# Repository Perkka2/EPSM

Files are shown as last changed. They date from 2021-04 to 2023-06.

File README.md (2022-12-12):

# EPSM
 NES Expansion Port Sound Module (Earlier: Expansion Port Sound Generator)

### An expansion sound card for the Nintendo Entertainment System

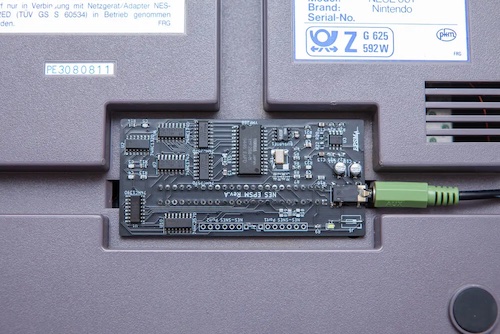
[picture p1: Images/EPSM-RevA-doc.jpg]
EPSM RevA


It uses an Yamaha YMF288 Soundchip that gives a lot of new audio capabilities to the NES.

## Features of YMF288:
* 3 Pulse Channels with Envelope and Noise
* 6 4OP FM Channels with hard panning stereo.
* 6 Rythm channels featuring 6 different ADPCM Drum Recordings with Hard Panning Stereo support
* 2 Timed IRQ's
## Added features of the EPSM
* Forwards expansion audio from supported gamecarts
  * Original Famicom expansion audio games with compatible adapter
  * PowerPak
  * EverDrive N8
  * EverDrive N8 Pro
  * Other carts using EXP2, EXP6 or EXP9 to output audio
* Alternative 3.5mm jack for Stereo output
  * EPSM Audio forwarding to the NES RCA/RF outputs are disabled when the 3.5mm jack is plugged in
  * NES Audio and Cart Expansion audio plays as Dual Mono on the 3.5mm jack.

## Tools
* Mesen-X: Supports playback of EPSM using any mapper.
* FamiStudio: Allows for music creation for the EPSM and has both ROM and NSF export options.

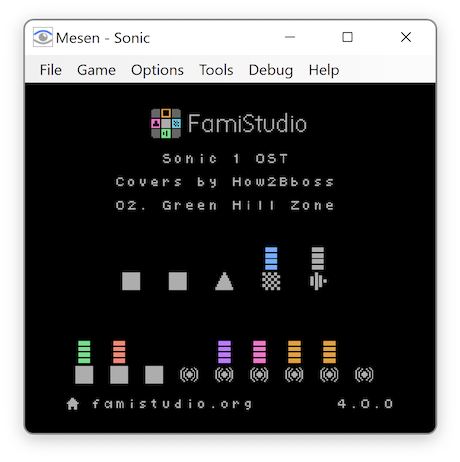
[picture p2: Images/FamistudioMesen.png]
Famistudio_and_Mesen


## Usage
* [Addressing](Docs/Addressing.md)
* [Addressing Fiskbit's Fallback Handler](Docs/Fiskbit-FallbackHandler.md)
* [NESDev wiki](https://www.nesdev.org/wiki/Expansion_Port_Sound_Module)
* [N8 Pro Mappers with EPSM Addressing](Files/N8ProEPSM.zip)

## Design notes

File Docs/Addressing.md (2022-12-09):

It uses 2 different addressing methods, either using the `$4016 OUT1` latch that exist on both NES and Famicom expansion port.
Or addresing throught the `EXP` pins on the NES or a external address daughterboard on the Famicom

It has two independent addressing modes
Firstly it got an addressing mode using the expansion port OUT1 signal

The OUT1 latch signal is used as a clock for the data transfer, it latches on writes to $4016.
On the OUT1 rising edge it takes CPU D2-D7 data bits D4-D7 and using it as the High Nibble
Data bit D2 is used to define if it's Register or Data
Data bit D3 is used to define if A1 is set (switching between SSG,Rythm,FM1-3 or FM4-6)

On the falling edge it takes CPU D4-D7 data bits and using it as the Low Nibble.
One important thing to think about is that OUT1 ONLY latches every other cpu cycle. so this needs to stay in sync.

The second addressing mode use addressing through the cartridge EXP pins for the NES, or the cart addressing connector on the Famicom
It uses 5 lines to set Chip Enable, A0 (Register/Data) and A1

### Example

```
EXP8 - EPSM CE1 = CPU A14
EXP3 - EPSM CE2 = ROMSEL
EXP1 - EPSM CE3 = R/W
EXP7 - EPSM A0  = CPU A13
EXP4 - EPSM A1  = CPU A1
```

When connected like this the EPSM will listen to C00x/E00x
C000 for register A1=0, C002 for register A1=1, E000 data A1=0, E002 data A1=1

###  Example code for $4016

```
;address write A1=0
LDA value
PHA
AND #$F0
ORA #$2
STA $4016
PLA
ROL
ROL
ROL
ROL
AND #$F0
STA $4016
;address write A1=1
LDA value
PHA
AND #$F0
ORA #$6
STA $4016
PLA
ROL
ROL
ROL
ROL
AND #$F0
STA $4016
;data write A1=0
LDA value
PHA
AND #$F0
ORA #$A
STA $4016
PLA
ROL
ROL
ROL
ROL
AND #$F0
STA $4016
;data write A1=1
LDA value
PHA
AND #$F0
ORA #$E
STA $4016
PLA
ROL
ROL
ROL
ROL
AND #$F0
STA $4016
```

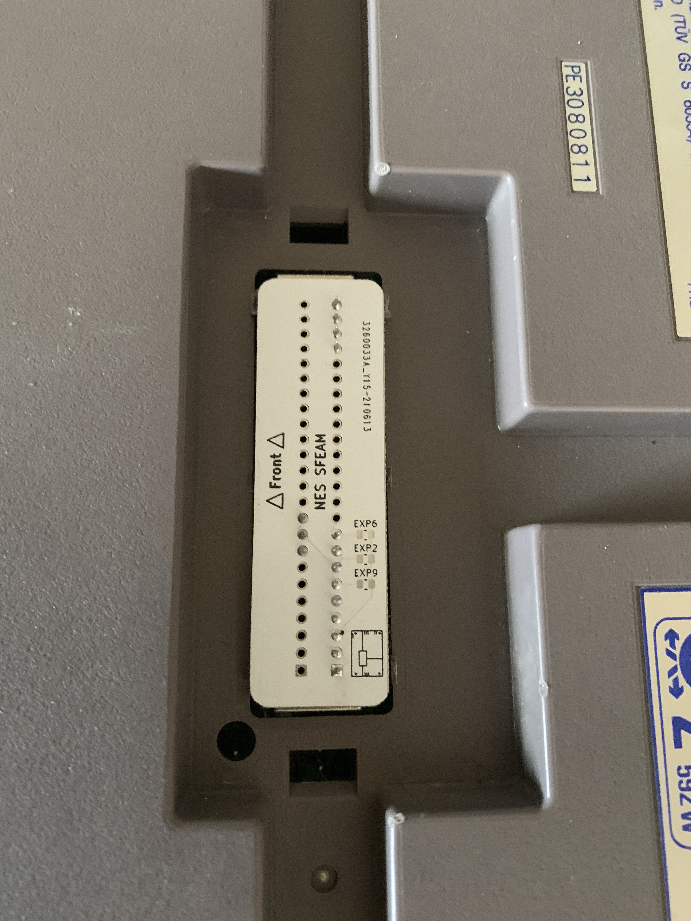
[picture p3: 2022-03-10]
Images/SFEAM_1.JPG

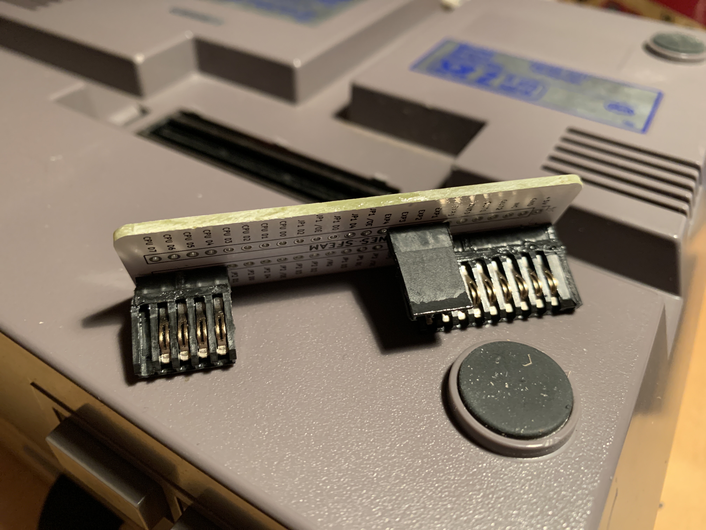
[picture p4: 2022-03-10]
Images/SFEAM_3.JPG

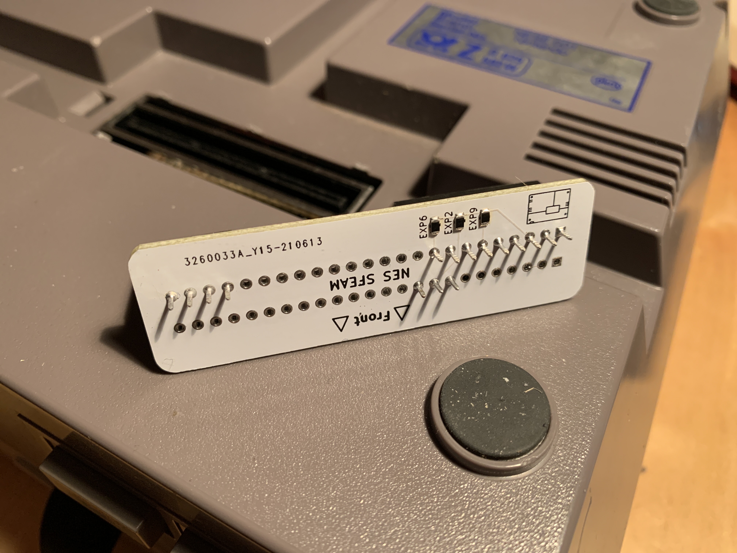
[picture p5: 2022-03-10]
Images/SFEAM_2.JPG

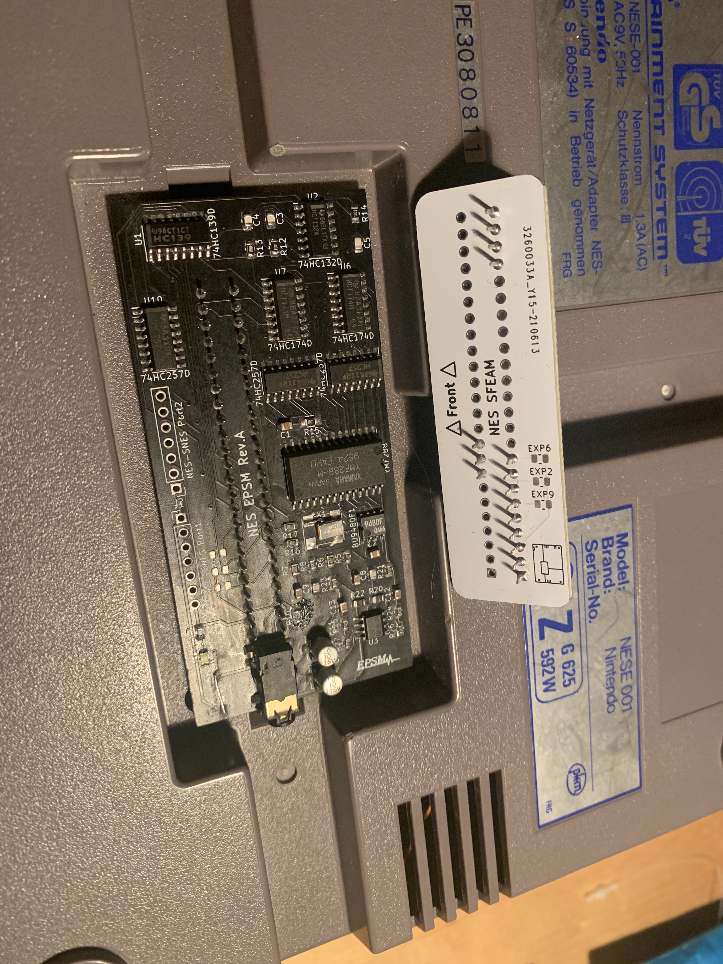
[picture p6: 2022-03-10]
Images/EPSM-RevA and SFEAM.JPG

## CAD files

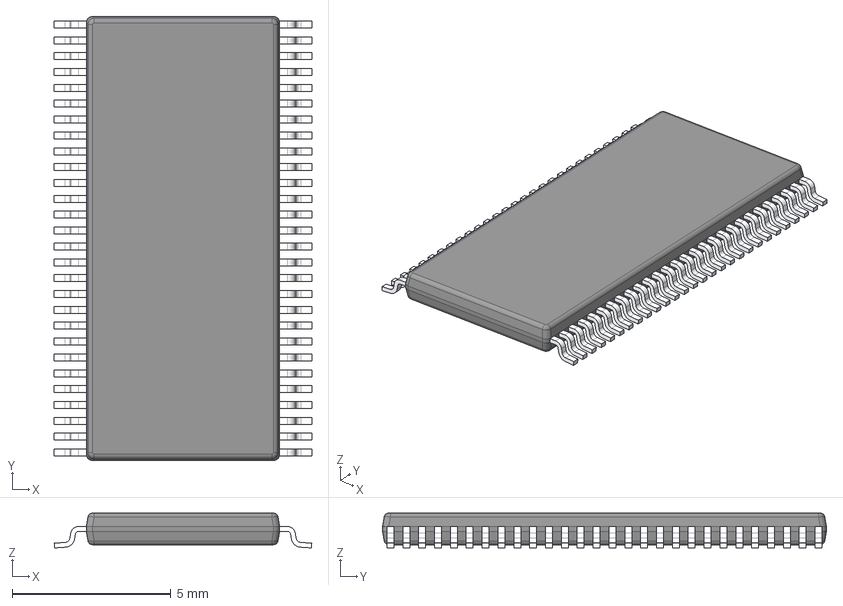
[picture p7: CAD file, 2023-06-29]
Nes Sound Expansion YMF288/eec.models/Texas_Instruments_-_SN74CBTLV16292GR.step
8.12 x 14.0 x 1.10 mm

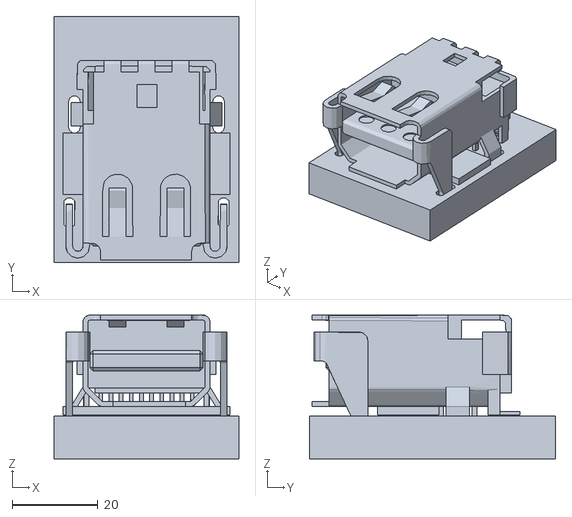
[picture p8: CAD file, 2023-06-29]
Nes Sound Expansion YMF288/Foxconn.models/OBJ_NEW_PCB.obj
43.0 x 57.2 x 33.4

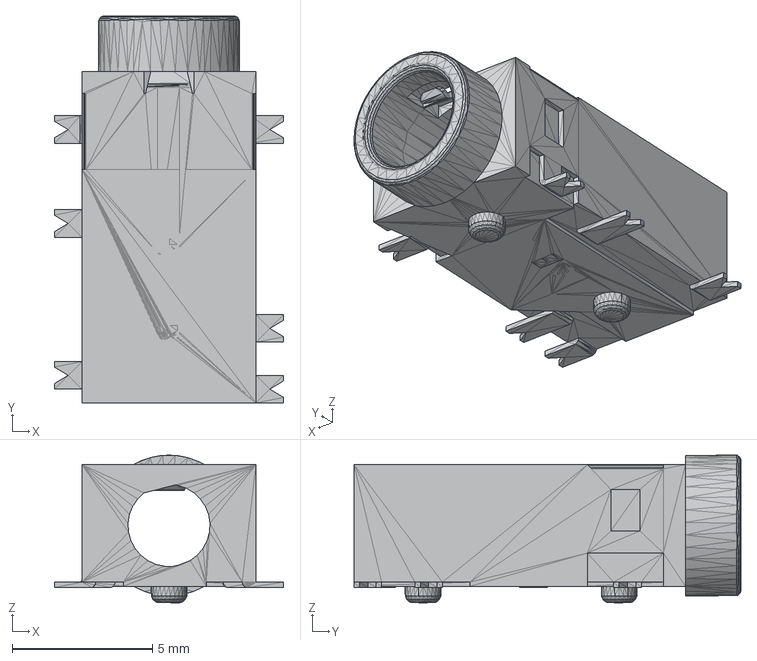
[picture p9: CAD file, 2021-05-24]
Nes Sound Expansion YMF288/walter/conn_av/PJ-342b.step
8.17 x 13.8 x 5.26 mm

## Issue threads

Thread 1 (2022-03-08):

Hello!

zombie343, 2022-03-08:
I've used KICAD and Gerber, but the other files just confuse me. Are these printed circuit boards? Why post on GitHub vs say, OSHpark? I feel like I'm missing something obvious that might be solved by a screenshot.

P.S. thank you for doing this, as I'm modding all of my various NESes, flash carts and converters to support expansion audio

Perkka2, 2022-03-08:
Which files are confusing you? I am having all my NES projects here on GitHub.
There are mainly 3 PCBs here. 2x EPSM's and 1 simple audio mod board to get ordinary expansion audio to the NES without modding the NES

zombie343, 2022-03-09:
Yes! I'm interested in the solderless expansion audio! Could I trouble you for 1-2 pictures? Can I have the solderless expansion board made via OSHpark or PCBWay?

Perkka2, 2022-03-10:
I have now uploaded some example images of the NES version of the EPSM and the SFEAM.

I have used jlcpcb for my boards but i can not see why you would have any issues with other producers

zombie343, 2022-03-11:
Thank you! I'm new to ordering PCBs so I appreciate the pictures and the recommendation!

zombie343, 2022-03-11:
Stupid question: does the console boot into the EPSM instead of the cartridge? Or does this replicate/replay the audio of the plugged-in cart?

Perkka2, 2022-05-18:
Discussion finished on discord

Closed 2022-05-18.

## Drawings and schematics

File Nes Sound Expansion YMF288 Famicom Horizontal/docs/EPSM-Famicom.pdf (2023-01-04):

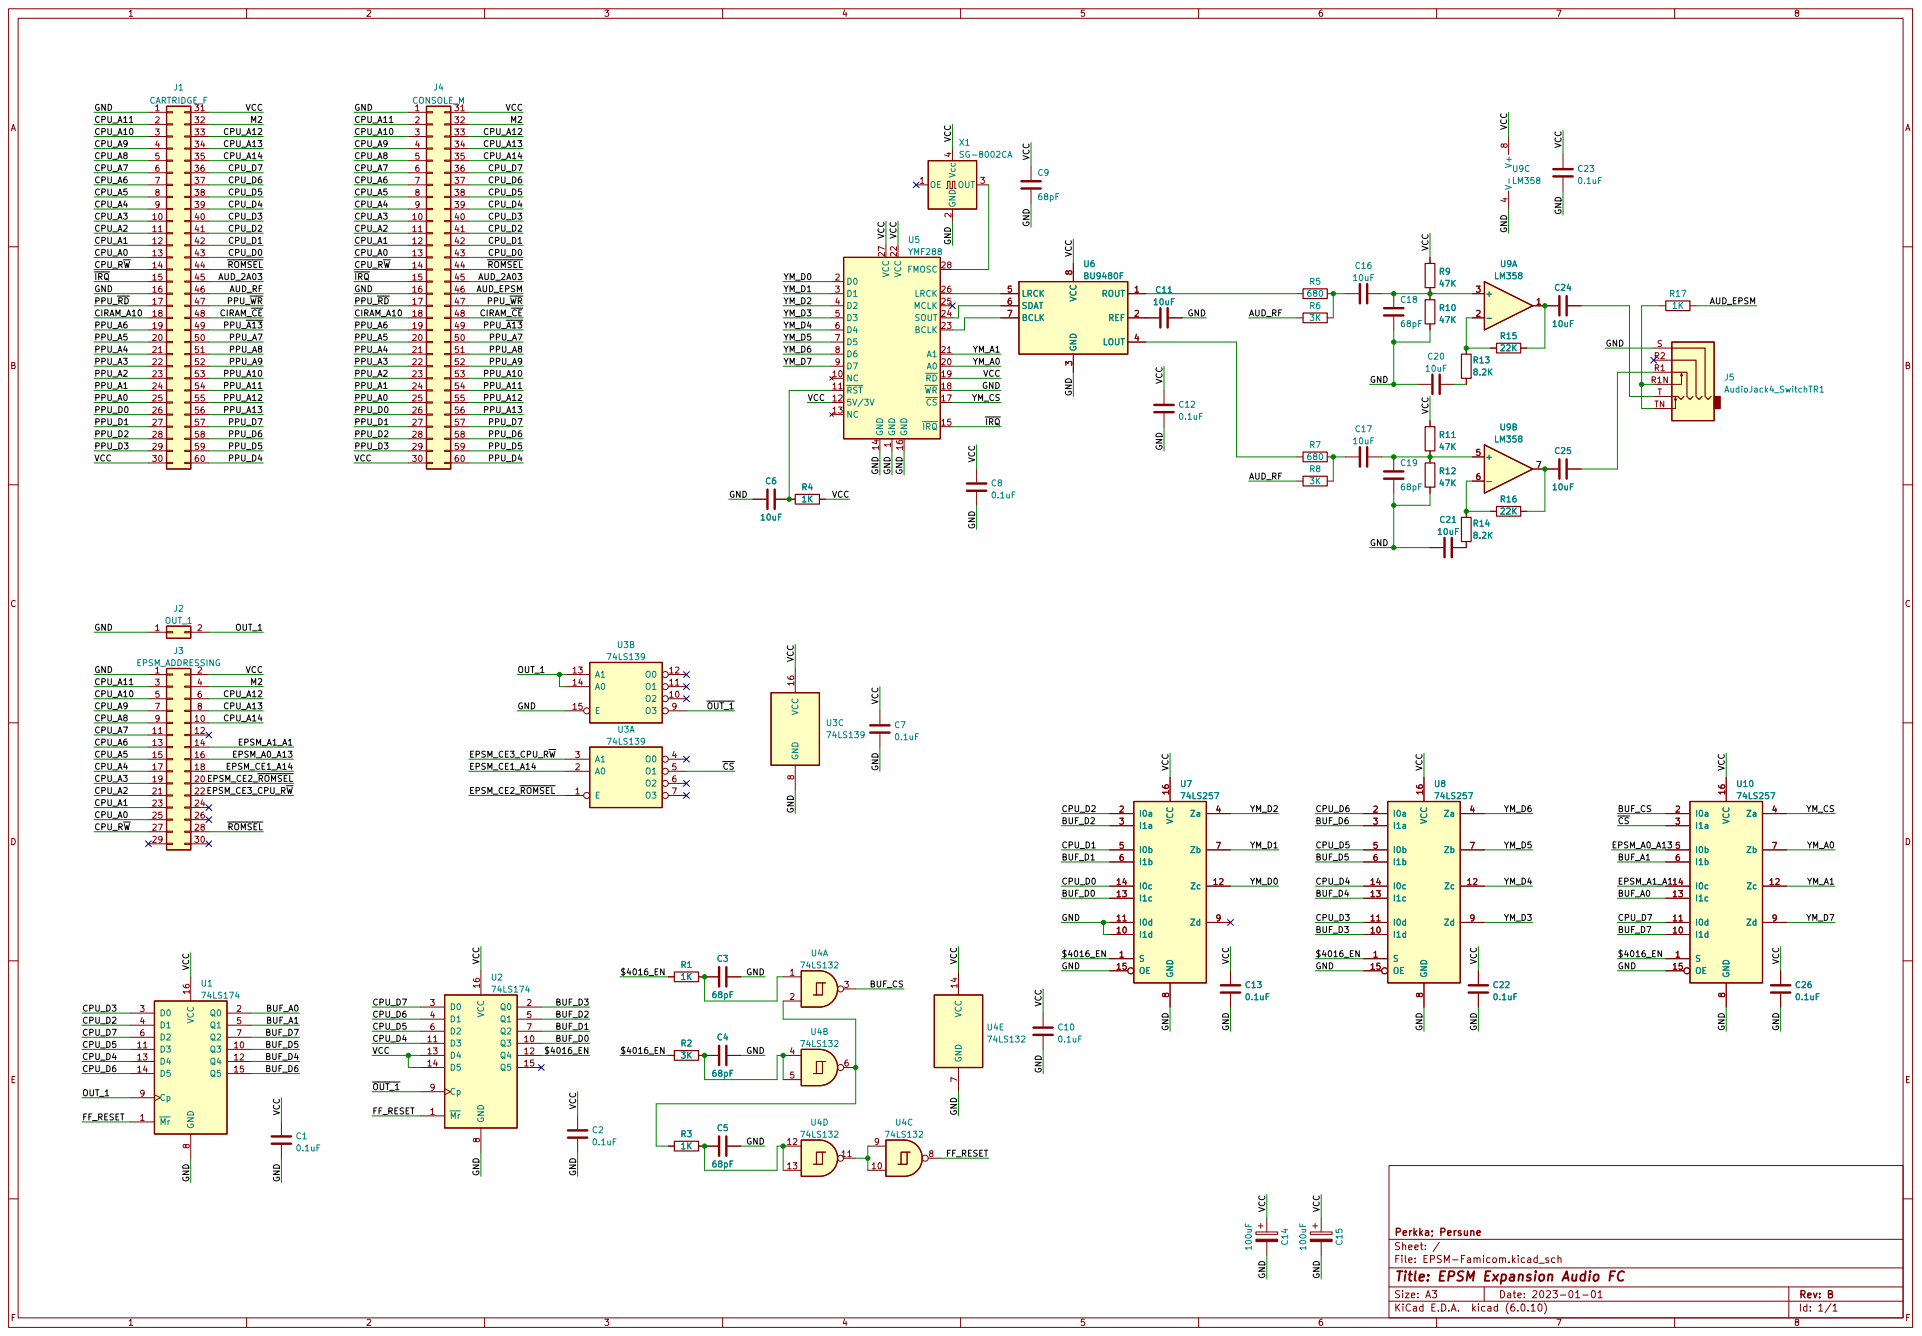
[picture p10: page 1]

GND VCC

File: EPSM-Famicom.kicad_sch Sheet: / Perkka; Persune

Id: 1/1 Title: EPSM Expansion Audio FC

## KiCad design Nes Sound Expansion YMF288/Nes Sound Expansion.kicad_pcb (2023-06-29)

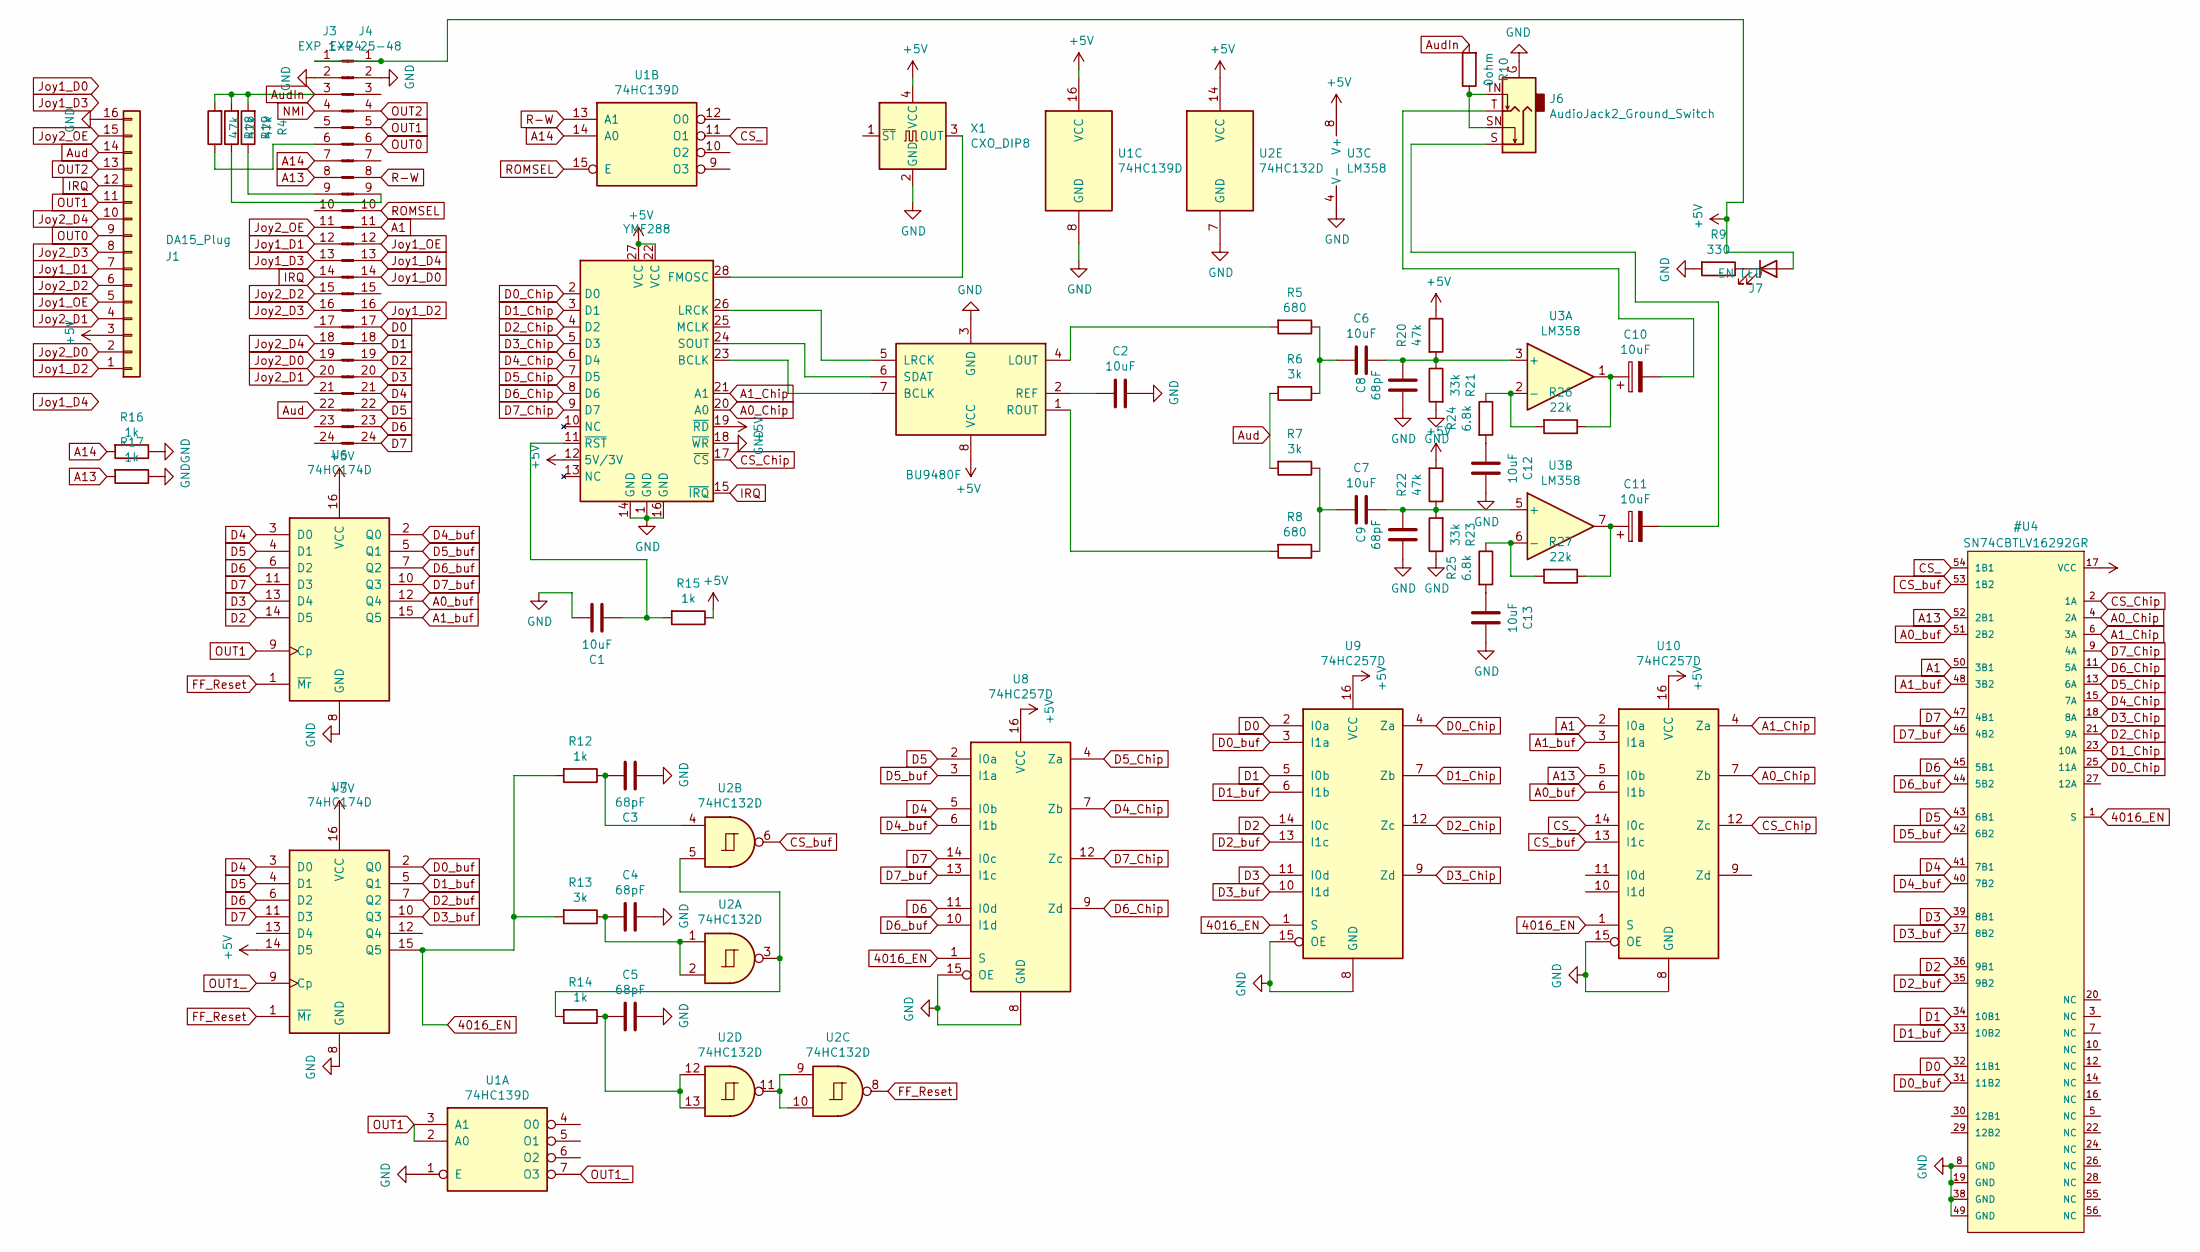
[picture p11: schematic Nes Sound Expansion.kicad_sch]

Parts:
BU9480F1: BU9480F; SOIC-8_3.9x4.9mm_P1.27mm
C1, C2, C6, C7, C12, C13: 10uF; C_0805_2012Metric
C3, C4, C5, C8, C9: 68pF; C_0603_1608Metric
C10, C11: 10uF; CP_Elec_4x5.3
J1: DA15_Plug; IDC-Header_2x08_P2.54mm_Vertical
J3: EXP 1-24; PinHeader_1x24_P2.54mm_Vertical
J4: EXP 25-48; PinHeader_1x24_P2.54mm_Vertical
J6: AudioJack2_Ground_Switch; Jack_3.5mm_PJ311_Horizontal_other_pinout
J7: EN LED; LED_0805_2012Metric
R4, R18, R19, R20, R22: 47k; R_0603_1608Metric
R5, R8: 680; R_0603_1608Metric
R6, R7, R13: 3k; R_0603_1608Metric
R9: 330; R_0603_1608Metric
R10: 0ohm; R_0603_1608Metric
R12, R14, R15, R16, R17: 1k; R_0603_1608Metric
R21, R23: 33k; R_0603_1608Metric
R24, R25: 6.8k; R_0603_1608Metric
R26, R27: 22k; R_0603_1608Metric
U1: 74HC139D; SOIC-16_3.9x9.9mm_P1.27mm
U2: 74HC132D; SOIC-14_3.9x8.7mm_P1.27mm
U3: LM358; SOIC-8_3.9x4.9mm_P1.27mm
U6, U7: 74HC174D; SOIC-16_3.9x9.9mm_P1.27mm
U8, U9, U10: 74HC257D; SOIC-16_3.9x9.9mm_P1.27mm
X1: CXO_DIP8; Oscillator_SMD_SeikoEpson_SG8002LB-4Pin_5.0x3.2mm
YMF288: YMF288

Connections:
A14: J3.7, R16.2, U1.14 (A0)
Aud: J1.14, J3.22, R6.2, R7.2
AudIn: J3.3, R4.2, R10.2, R18.2, R19.2
FF_Reset: U2.8, U6.1 (~Mr), U7.1 (~Mr)
IRQ: J1.12, J3.14, YMF288.15 (~IRQ)
Joy1_D0: J4.14
Joy1_D1: J1.7, J3.12
Joy1_D2: J1.1, J4.16
Joy1_D3: J3.13
Joy1_D4: J4.13
Joy1_OE: J1.5, J4.12
Joy2_D0: J1.2, J3.19
Joy2_D1: J1.4, J3.20
Joy2_D2: J1.6, J3.15
Joy2_D3: J1.8, J3.16
Joy2_D4: J1.10, J3.18
Joy2_OE: J1.15, J3.11
NMI: J3.4
unnamed: BU9480F1.7 (BCLK), YMF288.23 (BCLK)
unnamed: BU9480F1.4 (LOUT), R5.2
unnamed: BU9480F1.5 (LRCK), YMF288.26 (LRCK)
unnamed: BU9480F1.2 (REF), C2.1
unnamed: BU9480F1.1 (ROUT), R8.2
unnamed: BU9480F1.6 (SDAT), YMF288.24 (SOUT)
unnamed: C3.2, R12.1, U2.4
unnamed: C4.1, R13.1, U2.1, U2.2
unnamed: C5.1, R14.1, U2.12, U2.13
unnamed: C6.1, R5.1, R6.1
unnamed: C7.1, R7.1, R8.1
unnamed: C10.1, R26.1, U3.1
unnamed: C10.2, J6.T
unnamed: C11.1, R27.1, U3.7
unnamed: C11.2, J6.S
unnamed: C12.1, R24.2
unnamed: C13.1, R25.2
unnamed: J3.6, R18.1
unnamed: J3.9, R4.1
unnamed: J4.9, R19.1
unnamed: J6.SN, J6.TN, R10.1
unnamed: J7.1 (K), R9.1
unnamed: R14.2, U2.3, U2.5
unnamed: U2.9, U2.10, U2.11
unnamed: C6.2, C8.1, R20.2, R21.1, U3.3 (+)
unnamed: R24.1, R26.2, U3.2 (-)
unnamed: C7.2, C9.2, R22.1, R23.2, U3.5 (+)
unnamed: R25.1, R27.2, U3.6 (-)
unnamed: X1.3 (OUT), YMF288.28 (FMOSC)
unnamed: C1.1, R15.2, YMF288.11 (~RST)
OUT0: J1.9, J4.6
OUT1: J1.11, J4.5, U1.2 (A0), U1.3 (A1), U6.9 (Cp)
OUT1_: U1.7 (O3), U7.9 (Cp)
OUT2: J1.13, J4.4
R-W: J4.8, U1.13 (A1)
ROMSEL: J4.10, U1.15 (E)

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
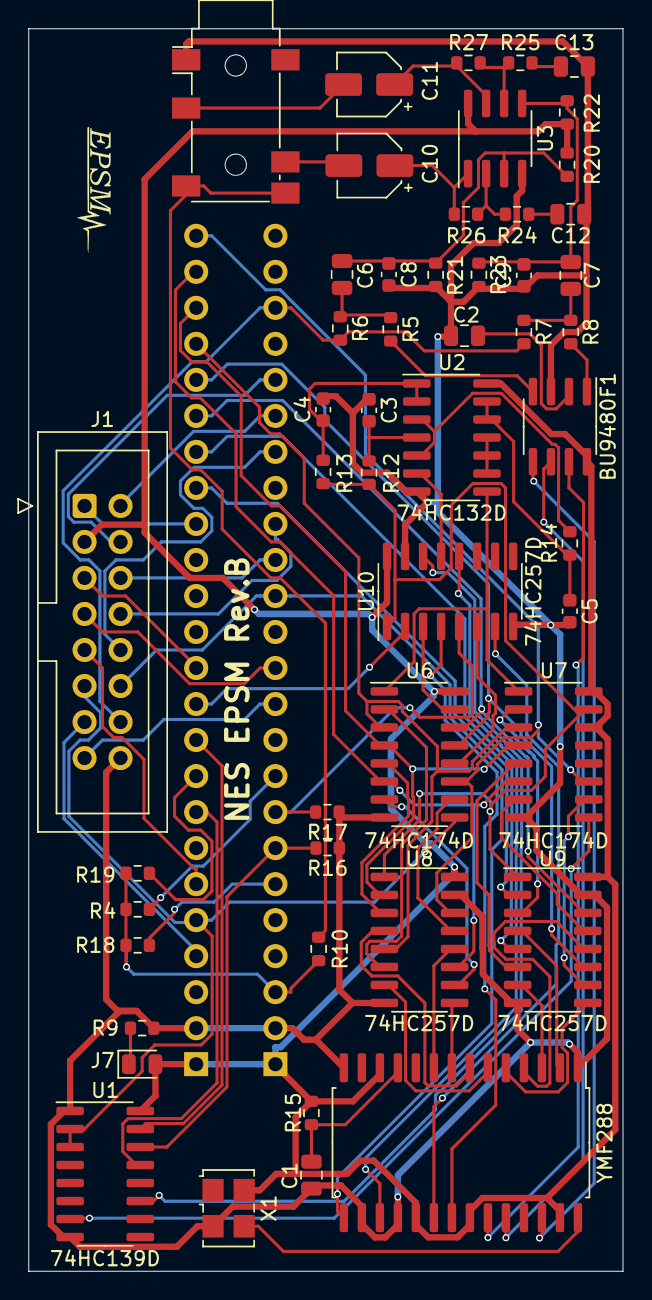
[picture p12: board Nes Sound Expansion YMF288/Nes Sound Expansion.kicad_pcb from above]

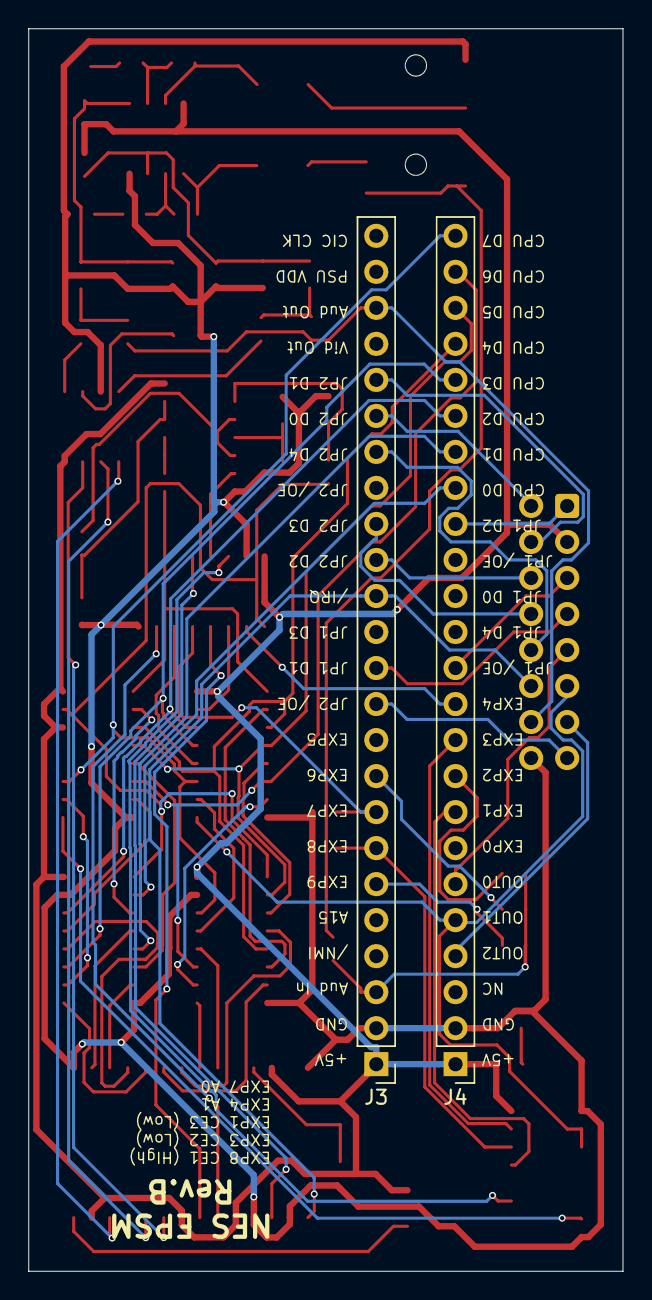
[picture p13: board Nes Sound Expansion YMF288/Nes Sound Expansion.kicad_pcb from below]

Board: 2 copper layers, 41.9 x 87.6 mm, 52 parts (2 on the bottom side), 86 nets.

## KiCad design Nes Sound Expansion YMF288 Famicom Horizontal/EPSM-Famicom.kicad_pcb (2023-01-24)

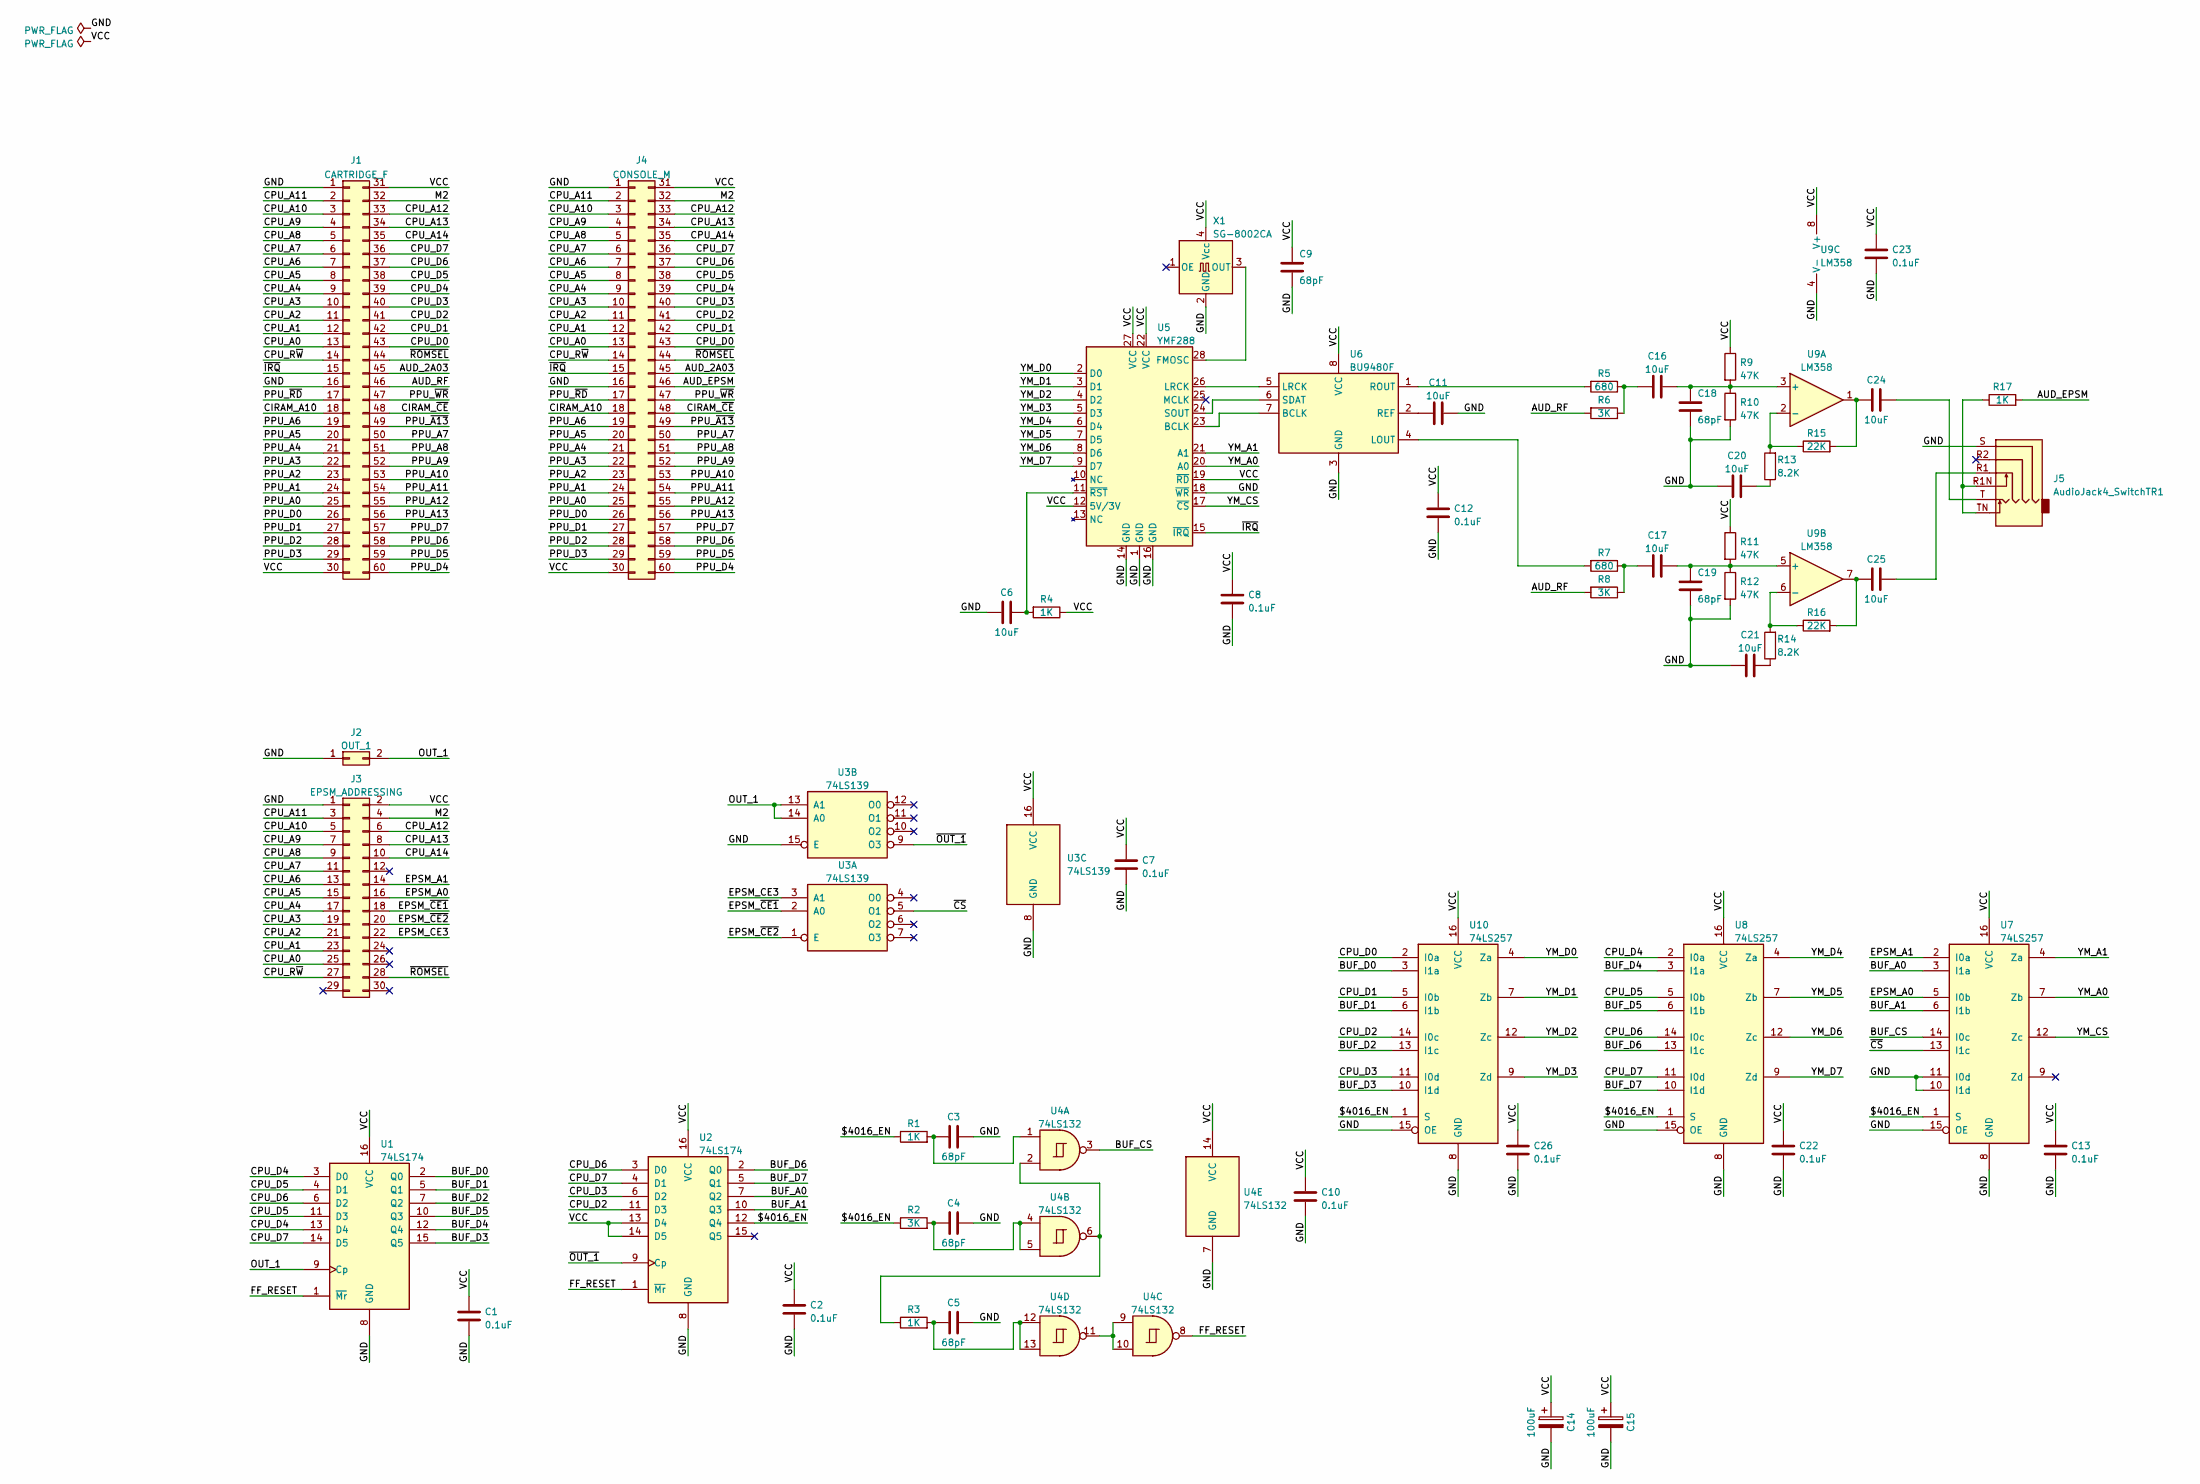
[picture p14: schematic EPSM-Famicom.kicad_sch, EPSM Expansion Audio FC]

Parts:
C1, C2, C7, C8, C10, C12, C13, C22, C23, C26: 0.1uF; C_0805_2012Metric_Pad1.18x1.45mm_HandSolder
C3, C4, C5, C9, C18, C19: 68pF; C_0805_2012Metric_Pad1.18x1.45mm_HandSolder
C6, C11, C16, C17, C20, C21, C24, C25: 10uF; C_0805_2012Metric_Pad1.18x1.45mm_HandSolder
C14, C15: 100uF; CP_Radial_D5.0mm_P2.50mm
J1: CARTRIDGE_F; FC_CONN_F
J2: OUT_1; PinHeader_1x02_P2.54mm_Vertical
J3: EPSM_ADDRESSING; PinSocket_2x15_P2.54mm_Vertical_SMD
J4: CONSOLE_M; HVC-ETROM-01
J5: AudioJack4_SwitchTR1; Jack_3.5mm_PJ311_Horizontal
R1, R3, R4, R17: 1K; R_0805_2012Metric_Pad1.20x1.40mm_HandSolder
R2, R6, R8: 3K; R_0805_2012Metric_Pad1.20x1.40mm_HandSolder
R5, R7: 680; R_0805_2012Metric_Pad1.20x1.40mm_HandSolder
R9, R10, R11, R12: 47K; R_0805_2012Metric_Pad1.20x1.40mm_HandSolder
R13, R14: 8.2K; R_0805_2012Metric_Pad1.20x1.40mm_HandSolder
R15, R16: 22K; R_0805_2012Metric_Pad1.20x1.40mm_HandSolder
U1, U2: 74LS174; SOIC-16_3.9x9.9mm_P1.27mm
U3: 74LS139; SOIC-16_3.9x9.9mm_P1.27mm
U4: 74LS132; SOIC-14_3.9x8.7mm_P1.27mm
U5: YMF288; SOP-28_7.5x12.8mm_P1.27mm
U6: BU9480F; SOIC-8_5.275x5.275mm_P1.27mm
U7, U8, U10: 74LS257; SOIC-16_3.9x9.9mm_P1.27mm
U9: LM358; SOIC-8_3.9x4.9mm_P1.27mm
X1: SG-8002CA; Oscillator_SMD_SeikoEpson_SG8002LB-4Pin_5.0x3.2mm

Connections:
/$4016_EN: R1.1, R2.1, U2.12 (Q4), U7.1 (S), U8.1 (S), U10.1 (S)
/AUD_2A03: J1.45, J4.45
/AUD_EPSM: J4.46, R17.2
/AUD_RF: J1.46, R6.2, R8.2
/BUF_A0: U2.7 (Q2), U7.3 (I1a)
/BUF_A1: U2.10 (Q3), U7.6 (I1b)
/BUF_CS: U4.3, U7.14 (I0c)
/BUF_D0: U1.2 (Q0), U10.3 (I1a)
/BUF_D1: U1.5 (Q1), U10.6 (I1b)
/BUF_D2: U1.7 (Q2), U10.13 (I1c)
/BUF_D3: U1.15 (Q5), U10.10 (I1d)
/BUF_D4: U1.12 (Q4), U8.3 (I1a)
/BUF_D5: U1.10 (Q3), U8.6 (I1b)
/BUF_D6: U2.2 (Q0), U8.13 (I1c)
/BUF_D7: U2.5 (Q1), U8.10 (I1d)
/CIRAM_A10: J1.18, J4.18
/CIRAM_~CE: J1.48, J4.48
/CPU_A0: J1.13, J3.25, J4.13
/CPU_A1: J1.12, J3.23, J4.12
/CPU_A2: J1.11, J3.21, J4.11
/CPU_A3: J1.10, J3.19, J4.10
/CPU_A4: J1.9, J3.17, J4.9
/CPU_A5: J1.8, J3.15, J4.8
/CPU_A6: J1.7, J3.13, J4.7
/CPU_A7: J1.6, J3.11, J4.6
/CPU_A8: J1.5, J3.9, J4.5
/CPU_A9: J1.4, J3.7, J4.4
/CPU_A10: J1.3, J3.5, J4.3
/CPU_A11: J1.2, J3.3, J4.2
/CPU_A12: J1.33, J3.6, J4.33
/CPU_A13: J1.34, J3.8, J4.34
/CPU_A14: J1.35, J3.10, J4.35
/CPU_D0: J1.43, J4.43, U10.2 (I0a)
/CPU_D1: J1.42, J4.42, U10.5 (I0b)
/CPU_D2: J1.41, J4.41, U2.11 (D3), U10.14 (I0c)
/CPU_D3: J1.40, J4.40, U2.6 (D2), U10.11 (I0d)
/CPU_D4: J1.39, J4.39, U1.3 (D0), U1.13 (D4), U8.2 (I0a)
/CPU_D5: J1.38, J4.38, U1.4 (D1), U1.11 (D3), U8.5 (I0b)
/CPU_D6: J1.37, J4.37, U1.6 (D2), U2.3 (D0), U8.14 (I0c)
/CPU_D7: J1.36, J4.36, U1.14 (D5), U2.4 (D1), U8.11 (I0d)
/CPU_R~W: J1.14, J3.27, J4.14
/EPSM_A0: J3.16, U7.5 (I0b)
/EPSM_A1: J3.14, U7.2 (I0a)
/EPSM_CE3: J3.22, U3.3 (A1)
/EPSM_~CE1: J3.18, U3.2 (A0)
/EPSM_~CE2: J3.20, U3.1 (E)
/FF_RESET: U1.1 (~Mr), U2.1 (~Mr), U4.8
/GND: C1.1, C2.1, C3.2, C4.2, C5.2, C6.1, C7.1, C8.1, C9.2, C10.1, C11.2, C12.1, C13.1, C14.2, C15.2, C18.2, C19.2, C20.1, C21.1, C22.1, C23.1, C26.1, J1.1, J1.16, J2.1, J3.1, J4.1, J4.16, J5.S, R10.2, R12.2, U1.8 (GND), U2.8 (GND), U3.8 (GND), U3.15 (E), U4.7 (GND), U5.1 (GND), U5.14 (GND), U5.16 (GND), U5.18 (~WR), U6.3 (GND), U7.8 (GND), U7.10 (I1d), U7.11 (I0d), U7.15 (OE), U8.8 (GND), U8.15 (OE), U9.4 (V-), U10.8 (GND), U10.15 (OE), X1.2 (GND)
/M2: J1.32, J3.4, J4.32
/OUT_1: J2.2, U1.9 (Cp), U3.13 (A1), U3.14 (A0)
/PPU_A0: J1.25, J4.25
/PPU_A1: J1.24, J4.24
/PPU_A2: J1.23, J4.23
/PPU_A3: J1.22, J4.22
/PPU_A4: J1.21, J4.21
/PPU_A5: J1.20, J4.20
/PPU_A6: J1.19, J4.19
/PPU_A7: J1.50, J4.50
/PPU_A8: J1.51, J4.51
/PPU_A9: J1.52, J4.52
/PPU_A10: J1.53, J4.53
/PPU_A11: J1.54, J4.54
/PPU_A12: J1.55, J4.55
/PPU_A13: J1.56, J4.56
/PPU_D0: J1.26, J4.26
/PPU_D1: J1.27, J4.27
/PPU_D2: J1.28, J4.28
/PPU_D3: J1.29, J4.29
/PPU_D4: J1.60, J4.60
/PPU_D5: J1.59, J4.59
/PPU_D6: J1.58, J4.58
/PPU_D7: J1.57, J4.57
/PPU_~A13: J1.49, J4.49
/PPU_~RD: J1.17, J4.17
/PPU_~WR: J1.47, J4.47
/VCC: C1.2, C2.2, C7.2, C8.2, C9.1, C10.2, C12.2, C13.2, C14.1, C15.1, C22.2, C23.2, C26.2, J1.30, J1.31, J3.2, J4.30, J4.31, R4.1, R9.1, R11.1, U1.16 (VCC), U2.13 (D4), U2.14 (D5), U2.16 (VCC), U3.16 (VCC), U4.14 (VCC), U5.12 (5V/3V), U5.19 (~RD), U5.22 (VCC), U5.27 (VCC), U6.8 (VCC), U7.16 (VCC), U8.16 (VCC), U9.8 (V+), U10.16 (VCC), X1.4 (Vcc)
/YM_A0: U5.20 (A0), U7.7 (Zb)
/YM_A1: U5.21 (A1), U7.4 (Za)
/YM_CS: U5.17 (~CS), U7.12 (Zc)
/YM_D0: U5.2 (D0), U10.4 (Za)
/YM_D1: U5.3 (D1), U10.7 (Zb)
/YM_D2: U5.4 (D2), U10.12 (Zc)
/YM_D3: U5.5 (D3), U10.9 (Zd)
/YM_D4: U5.6 (D4), U8.4 (Za)
/YM_D5: U5.7 (D5), U8.7 (Zb)
/YM_D6: U5.8 (D6), U8.12 (Zc)
/YM_D7: U5.9 (D7), U8.9 (Zd)
/~CS: U3.5 (O1), U7.13 (I1c)
/~IRQ: J1.15, J4.15, U5.15 (~IRQ)
/~OUT_1: U2.9 (Cp), U3.9 (O3)
/~ROMSEL: J1.44, J3.28, J4.44
unnamed: C3.1, R1.2, U4.1
unnamed: C4.1, R2.2, U4.4, U4.5
unnamed: C5.1, R3.2, U4.12, U4.13
unnamed: C6.2, R4.2, U5.11 (~RST)
unnamed: C11.1, U6.2 (REF)
unnamed: C16.1, R5.1, R6.1
unnamed: C16.2, C18.1, R9.2, R10.1, U9.3 (+)
unnamed: C17.1, R7.1, R8.1
unnamed: C17.2, C19.1, R11.2, R12.1, U9.5 (+)
unnamed: C20.2, R13.1
unnamed: C21.2, R14.1
unnamed: C24.1, R15.2, U9.1
unnamed: C24.2, J5.T
unnamed: C25.1, R16.2, U9.7
unnamed: C25.2, J5.R1
unnamed: J5.R1N, J5.TN, R17.1
unnamed: R3.1, U4.2, U4.6
unnamed: R5.2, U6.1 (ROUT)
unnamed: R7.2, U6.4 (LOUT)
unnamed: R13.2, R15.1, U9.2 (-)
unnamed: R14.2, R16.1, U9.6 (-)
unnamed: U4.9, U4.10, U4.11
unnamed: U5.23 (BCLK), U6.7 (BCLK)
unnamed: U5.24 (SOUT), U6.6 (SDAT)
unnamed: U5.26 (LRCK), U6.5 (LRCK)
unnamed: U5.28 (FMOSC), X1.3 (OUT)

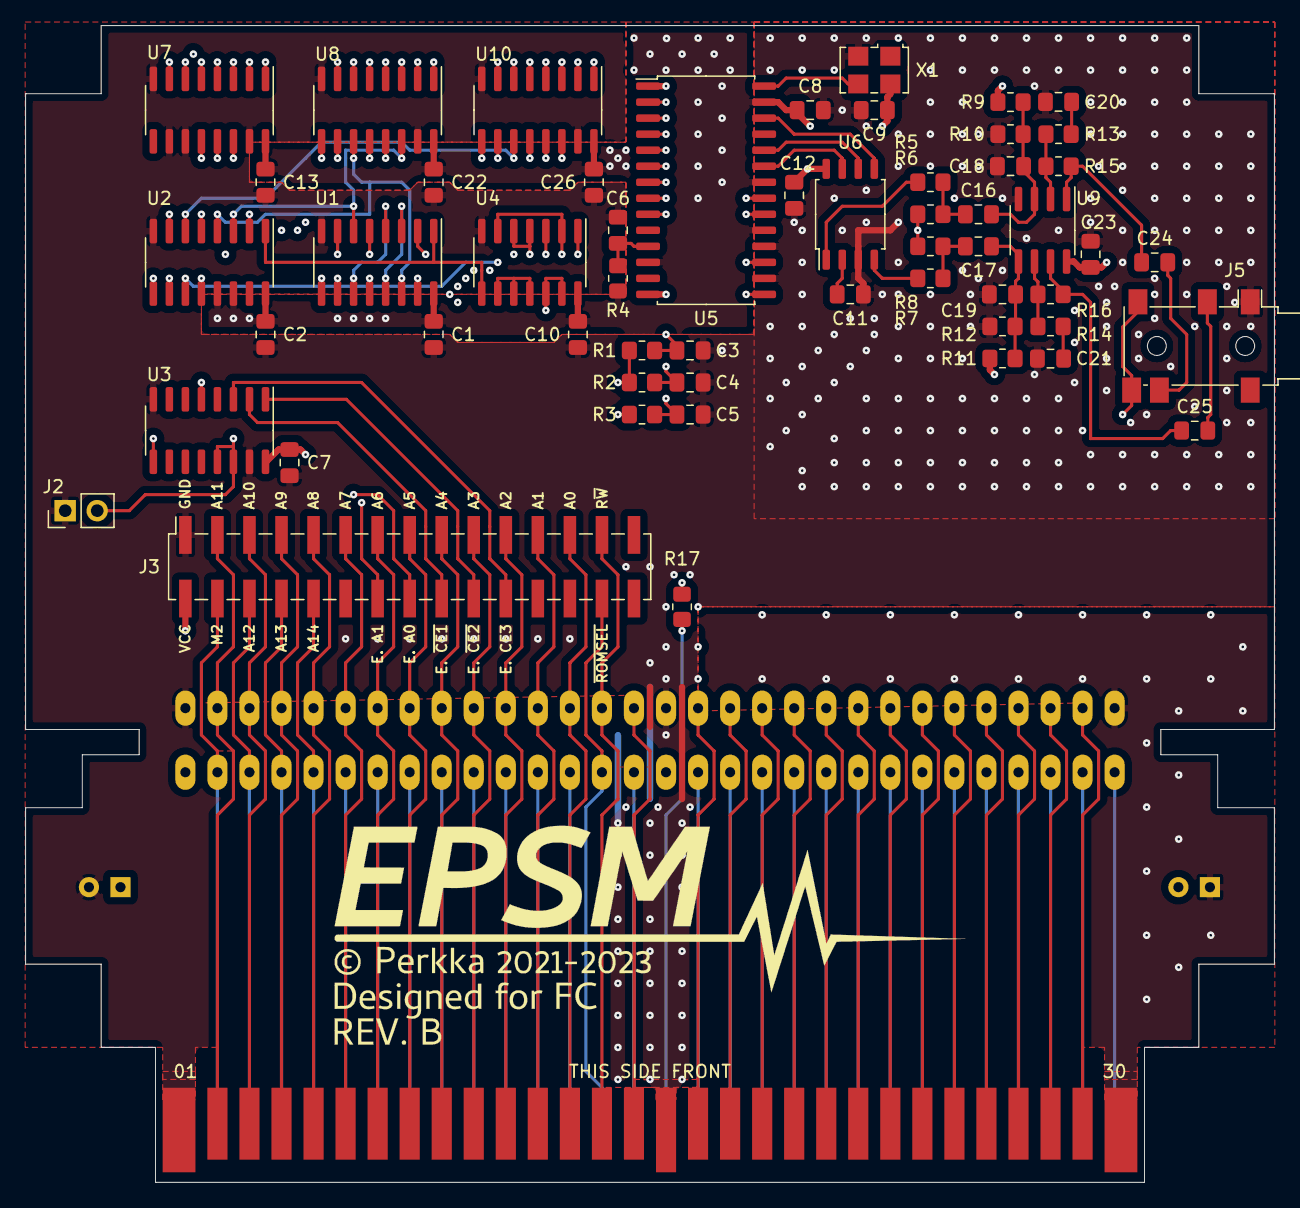
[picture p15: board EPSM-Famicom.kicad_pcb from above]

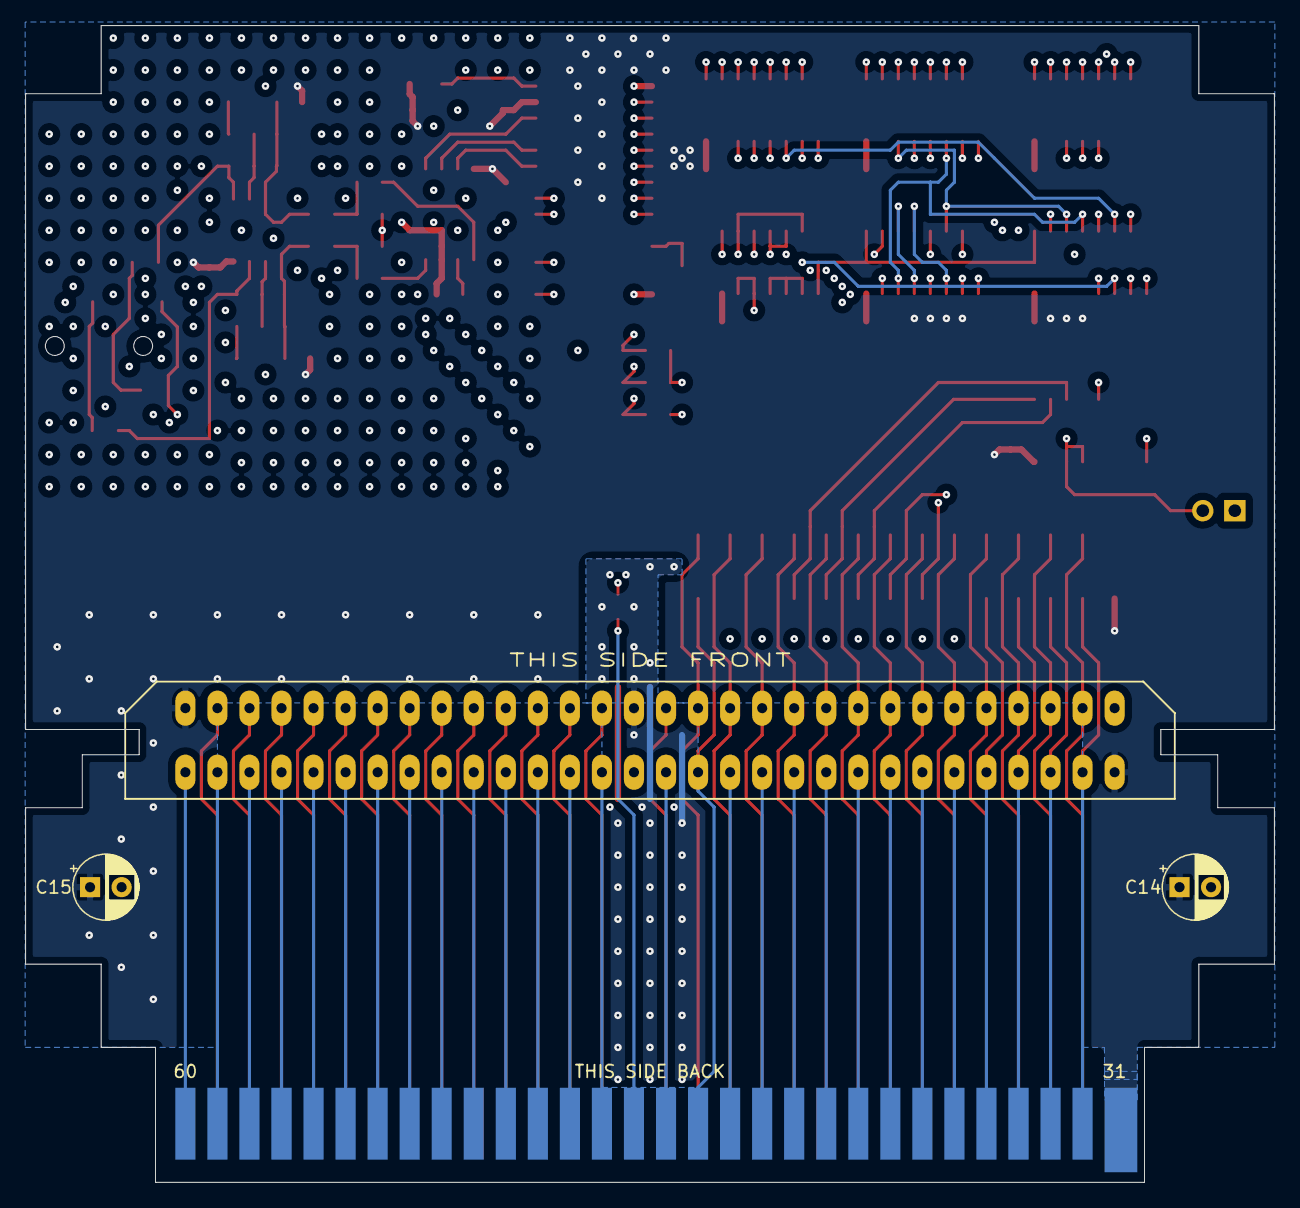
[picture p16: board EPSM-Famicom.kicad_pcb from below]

Board: 4 copper layers, 99.0 x 91.7 mm, 60 parts (3 on the bottom side), 117 nets.

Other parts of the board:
Ref**: Val**; EPSM_silkscreen

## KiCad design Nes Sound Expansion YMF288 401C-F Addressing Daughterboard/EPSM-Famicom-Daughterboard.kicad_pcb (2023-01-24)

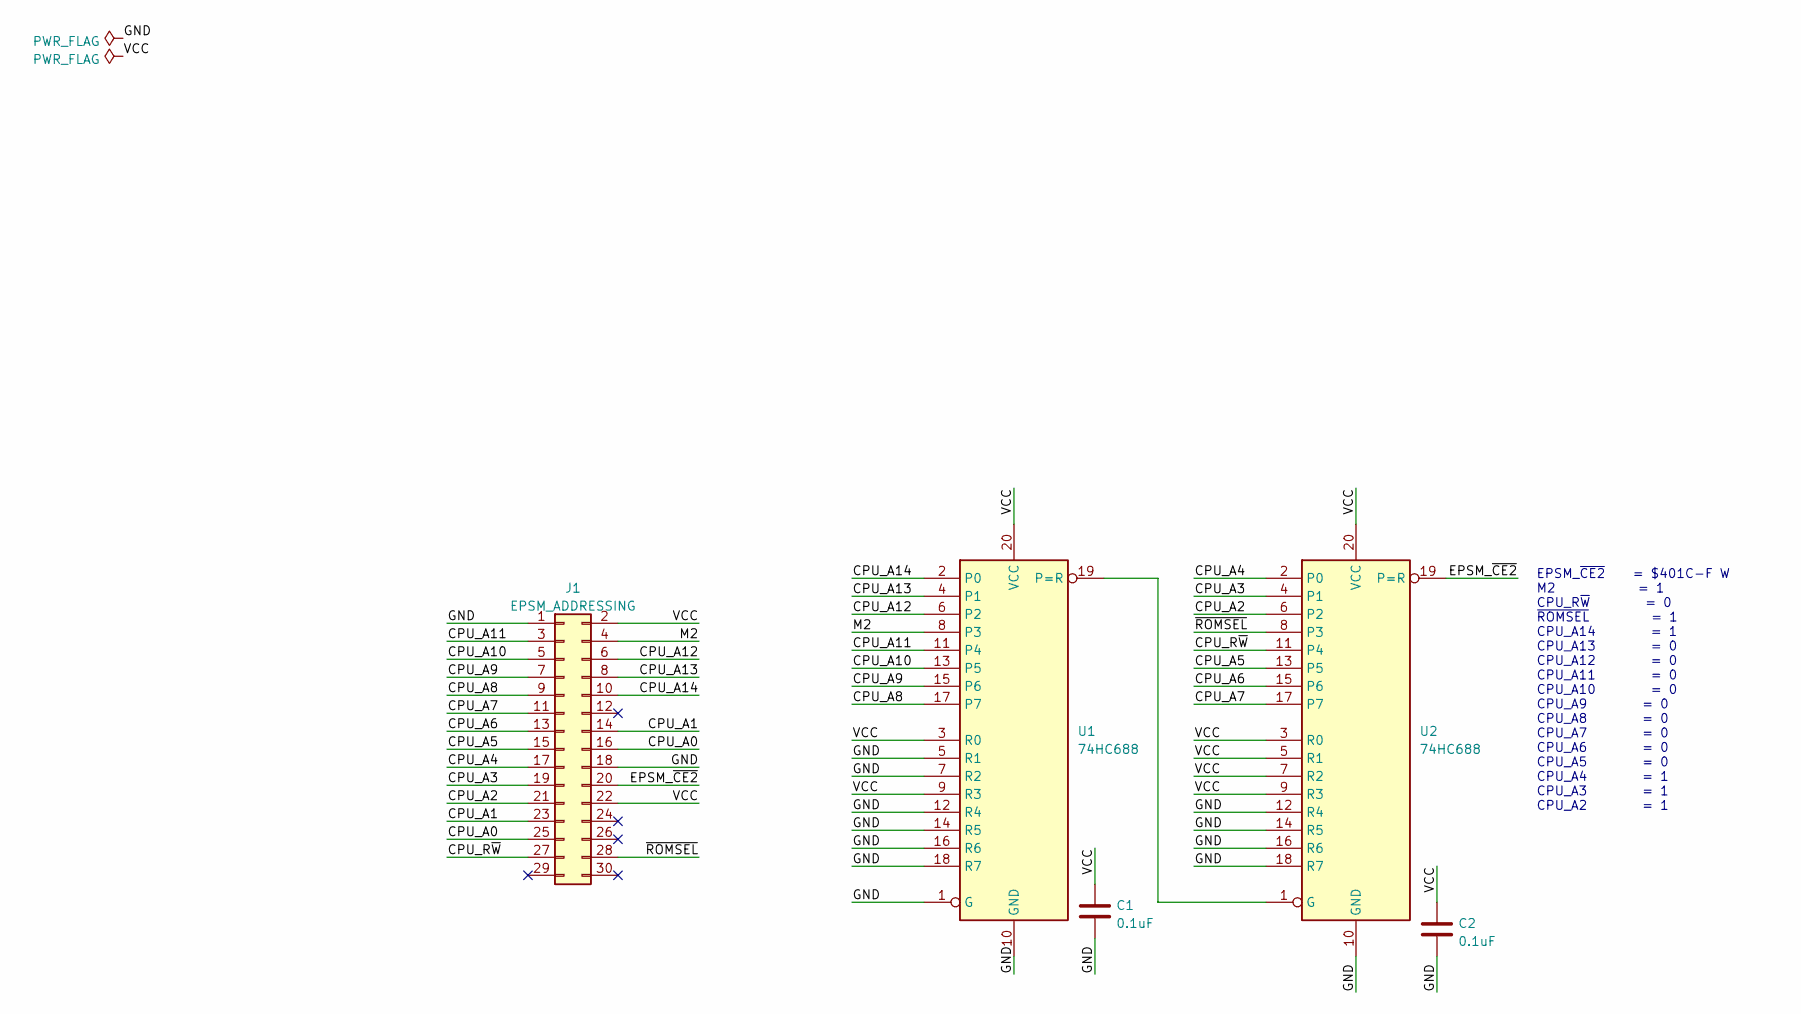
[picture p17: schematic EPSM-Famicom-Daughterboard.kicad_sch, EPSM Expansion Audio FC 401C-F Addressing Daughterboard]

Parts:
C1, C2: 0.1uF; C_0805_2012Metric_Pad1.18x1.45mm_HandSolder
J1: EPSM_ADDRESSING; PinHeader_2x15_P2.54mm_Vertical
U1, U2: 74HC688; SOIC-20W_7.5x12.8mm_P1.27mm

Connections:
/CPU_A0: J1.16, J1.25
/CPU_A1: J1.14, J1.23
/CPU_A2: J1.21, U2.6 (P2)
/CPU_A3: J1.19, U2.4 (P1)
/CPU_A4: J1.17, U2.2 (P0)
/CPU_A5: J1.15, U2.13 (P5)
/CPU_A6: J1.13, U2.15 (P6)
/CPU_A7: J1.11, U2.17 (P7)
/CPU_A8: J1.9, U1.17 (P7)
/CPU_A9: J1.7, U1.15 (P6)
/CPU_A10: J1.5, U1.13 (P5)
/CPU_A11: J1.3, U1.11 (P4)
/CPU_A12: J1.6, U1.6 (P2)
/CPU_A13: J1.8, U1.4 (P1)
/CPU_A14: J1.10, U1.2 (P0)
/CPU_R~W: J1.27, U2.11 (P4)
/EPSM_~CE2: J1.20, U2.19 (P=R)
/GND: C1.1, C2.1, J1.1, J1.18, U1.1 (G), U1.5 (R1), U1.7 (R2), U1.10 (GND), U1.12 (R4), U1.14 (R5), U1.16 (R6), U1.18 (R7), U2.10 (GND), U2.12 (R4), U2.14 (R5), U2.16 (R6), U2.18 (R7)
/M2: J1.4, U1.8 (P3)
/VCC: C1.2, C2.2, J1.2, J1.22, U1.3 (R0), U1.9 (R3), U1.20 (VCC), U2.3 (R0), U2.5 (R1), U2.7 (R2), U2.9 (R3), U2.20 (VCC)
/~ROMSEL: J1.28, U2.8 (P3)
unnamed: U1.19 (P=R), U2.1 (G)

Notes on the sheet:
EPSM_~{CE2} = $401C-F W M2 = 1 CPU_R~{W} = 0 ~{ROMSEL} = 1 CPU_A14 = 1 CPU_A13 = 0 CPU_A12 = 0 CPU_A11 = 0 CPU_A10 = 0 CPU_A9 = 0 CPU_A8 = 0 CPU_A7 = 0 CPU_A6 = 0 CPU_A5 = 0 CPU_A4 = 1 CPU_A3 = 1 CPU_A2 = 1

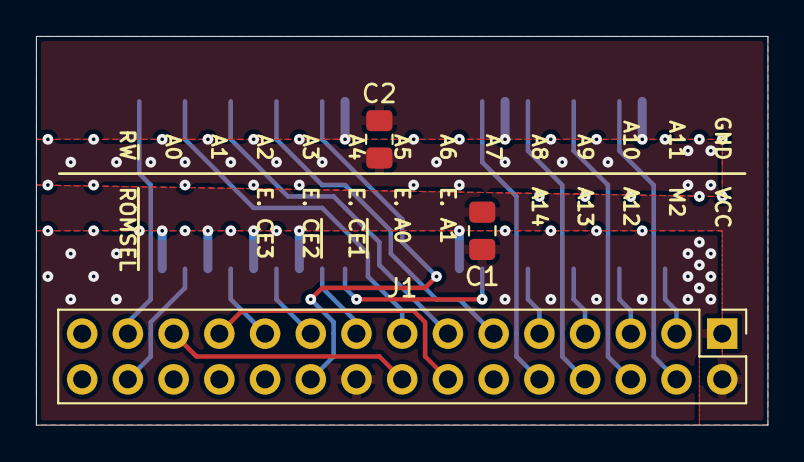
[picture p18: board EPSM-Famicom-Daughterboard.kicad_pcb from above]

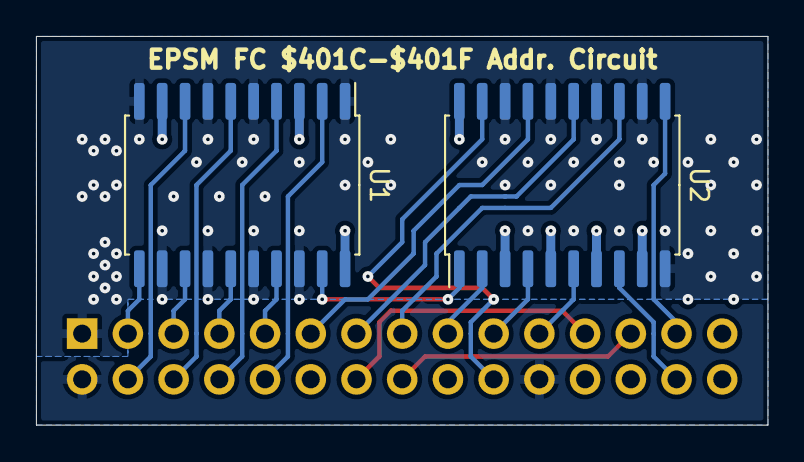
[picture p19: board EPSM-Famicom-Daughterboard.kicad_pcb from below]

Board: 2 copper layers, 40.6 x 21.6 mm, 5 parts (2 on the bottom side), 22 nets.

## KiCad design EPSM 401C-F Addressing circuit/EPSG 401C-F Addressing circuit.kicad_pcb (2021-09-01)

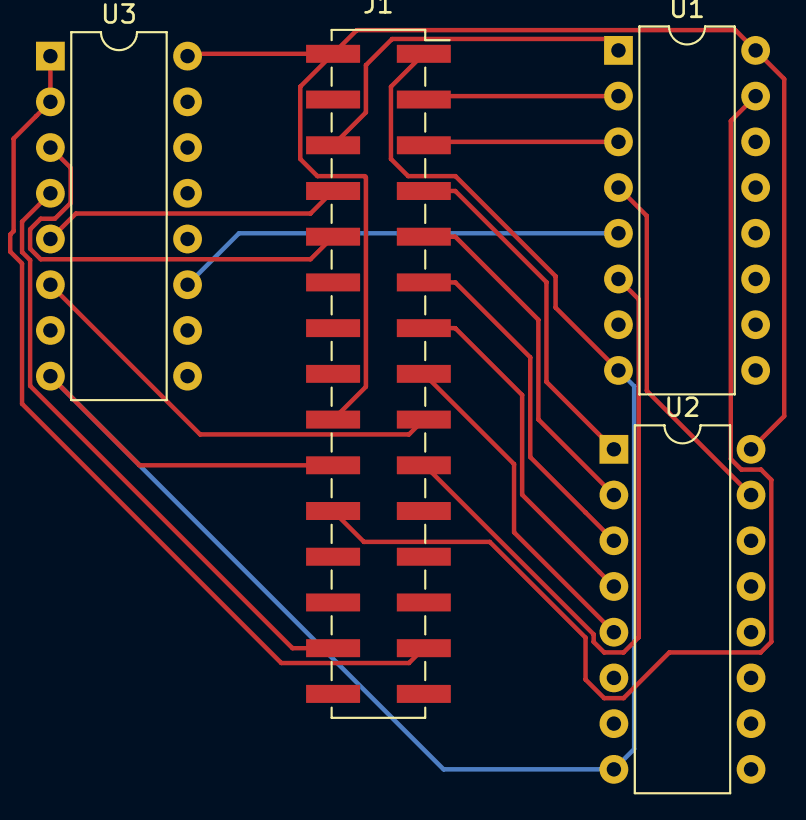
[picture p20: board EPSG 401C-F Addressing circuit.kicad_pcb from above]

Board: 2 copper layers, 4 parts (0 on the bottom side), 22 nets.

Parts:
J1: Conn_01x16_Female; PinSocket_2x15_P2.54mm_Vertical_SMD
U1, U2, U3: 74LS138; DIP-16_W7.62mm

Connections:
A0: J1.16, J1.25
A1: J1.14, J1.23
A2: J1.21, U2.6
A3: J1.19, U1.6
A4: J1.17, U3.6
A5: J1.15, U2.5
A6: J1.13, U2.4
A7: J1.11, U2.3
A8: J1.9, U2.2
A9: J1.7, U2.1
A10: J1.5, U1.3
A11: J1.3, U1.2
A12: J1.6, U1.1
A13: J1.8, U3.5
A14: J1.10, U3.3
EN1: U1.4, U2.15
EN2: U1.5, U3.11
EXP1: J1.1, J1.20, U1.8, U2.8, U3.8
EXP3: J1.22, U1.15
EXP8: J1.2, J1.18, U1.16, U2.16, U3.16
R-W: J1.27, U3.1, U3.2
ROMSEL: J1.28, U3.4

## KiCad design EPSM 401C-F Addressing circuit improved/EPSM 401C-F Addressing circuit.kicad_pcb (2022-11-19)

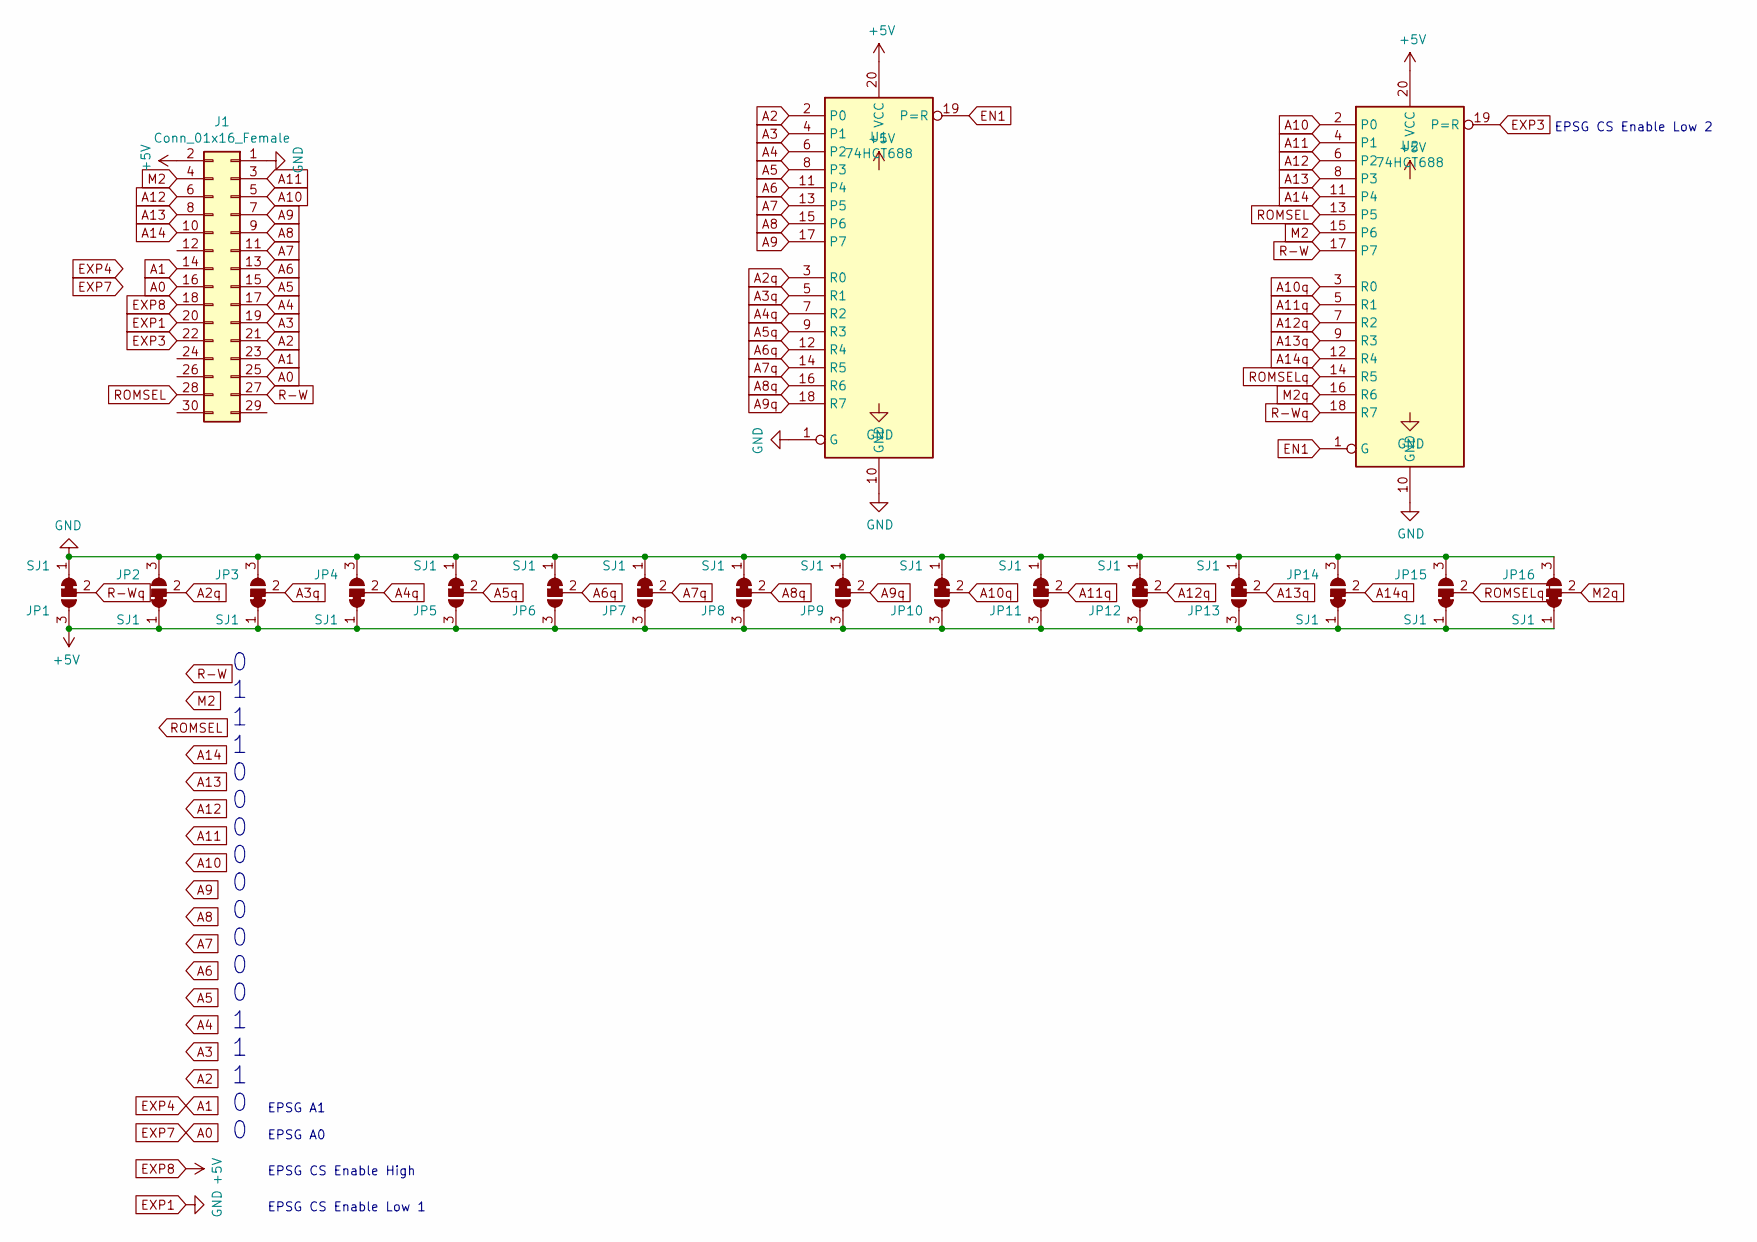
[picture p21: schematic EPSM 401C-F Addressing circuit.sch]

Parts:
J1: Conn_01x16_Female; PinSocket_2x15_P2.54mm_Vertical_SMD
JP1, JP2, JP3, JP4, JP5, JP6, JP7, JP8, JP9, JP10, JP11, JP12, JP13, JP14, JP15, JP16: SJ1; SolderJumper-3_P1.3mm_Bridged12_RoundedPad1.0x1.5mm
U1, U2: 74HCT688; SMDIP-20_W9.53mm_Clearance8mm

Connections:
A0: J1.16, J1.25
A1: J1.14, J1.23
A2: J1.21, U1.2 (P0)
A2q: JP2.2 (C), U1.3 (R0)
A3: J1.19, U1.4 (P1)
A3q: JP3.2 (C), U1.5 (R1)
A4: J1.17, U1.6 (P2)
A4q: JP4.2 (C), U1.7 (R2)
A5: J1.15, U1.8 (P3)
A5q: JP5.2 (C), U1.9 (R3)
A6: J1.13, U1.11 (P4)
A6q: JP6.2 (C), U1.12 (R4)
A7: J1.11, U1.13 (P5)
A7q: JP7.2 (C), U1.14 (R5)
A8: J1.9, U1.15 (P6)
A8q: JP8.2 (C), U1.16 (R6)
A9: J1.7, U1.17 (P7)
A9q: JP9.2 (C), U1.18 (R7)
A10: J1.5, U2.2 (P0)
A10q: JP10.2 (C), U2.3 (R0)
A11: J1.3, U2.4 (P1)
A11q: JP11.2 (C), U2.5 (R1)
A12: J1.6, U2.6 (P2)
A12q: JP12.2 (C), U2.7 (R2)
A13: J1.8, U2.8 (P3)
A13q: JP13.2 (C), U2.9 (R3)
A14: J1.10, U2.11 (P4)
A14q: JP14.2 (C), U2.12 (R4)
EN1: U1.19 (P=R), U2.1 (G)
EXP1: J1.1, J1.20, JP1.1 (A), JP2.3 (B), JP3.3 (B), JP4.3 (B), JP5.1 (A), JP6.1 (A), JP7.1 (A), JP8.1 (A), JP9.1 (A), JP10.1 (A), JP11.1 (A), JP12.1 (A), JP13.1 (A), JP14.3 (B), JP15.3 (B), JP16.3 (B), U1.1 (G), U1.10 (GND), U2.10 (GND)
EXP3: J1.22, U2.19 (P=R)
EXP8: J1.2, J1.18, JP1.3 (B), JP2.1 (A), JP3.1 (A), JP4.1 (A), JP5.3 (B), JP6.3 (B), JP7.3 (B), JP8.3 (B), JP9.3 (B), JP10.3 (B), JP11.3 (B), JP12.3 (B), JP13.3 (B), JP14.1 (A), JP15.1 (A), JP16.1 (A), U1.20 (VCC), U2.20 (VCC)
M2: J1.4, U2.15 (P6)
M2q: JP16.2 (C), U2.16 (R6)
R-W: J1.27, U2.17 (P7)
R-Wq: JP1.2 (C), U2.18 (R7)
ROMSEL: J1.28, U2.13 (P5)
ROMSELq: JP15.2 (C), U2.14 (R5)

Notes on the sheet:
0 1 1 1 0 0 0 0 0 0 0 0 0 1 1 1 0 0
EPSG A1
EPSG A0
EPSG CS Enable High
EPSG CS Enable Low 1
EPSG CS Enable Low 2

Board: 2 copper layers, 19 parts (0 on the bottom side), 38 nets, no tracks yet.

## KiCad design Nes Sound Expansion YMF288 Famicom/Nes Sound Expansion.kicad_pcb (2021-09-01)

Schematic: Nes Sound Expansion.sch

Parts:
BU9480F1: BU9480F; SOIC-8_5.275x5.275mm_P1.27mm
C1, C6, C8, C9: 10uF; C_0504_1310Metric_Pad0.83x1.28mm_HandSolder
C2: 10u; CP_Elec_4x5.3
C3, C4, C5, C7: 68pF; C_0504_1310Metric_Pad0.83x1.28mm_HandSolder
J1: OUT; PinHeader_1x02_P2.54mm_Vertical
J2: EXP 1-30; PinSocket_2x15_P2.54mm_Vertical_SMD
J3: EXP 1-30; Famicon CardEdge
J4: 31-60; Famicon CardEdge
J8: EXP 25-48; Famicon CardEdge
J9: EXP 1-24; Famicon CardEdge
R1, R2, R7: 47k; R_0805_2012Metric_Pad1.20x1.40mm_HandSolder
R3: 4.7k; R_0805_2012Metric_Pad1.20x1.40mm_HandSolder
R4, R5, R8, R9, R12, R13, R14: 1k; R_0805_2012Metric_Pad1.20x1.40mm_HandSolder
R6: 3k; R_0805_2012Metric_Pad1.20x1.40mm_HandSolder
U1: 74LS139; SOIC-16_3.9x9.9mm_P1.27mm
U2: 74LS132; SOIC-14_3.9x8.7mm_P1.27mm
U3: LM321; SOT-23-5
U6, U7: 74LS174; SOIC-16_3.9x9.9mm_P1.27mm
U8, U9, U10: 74LS257; SOIC-16_3.9x9.9mm_P1.27mm
X1: CXO_DIP8; Oscillator_SMD_SeikoEpson_SG8002CA-4Pin_7.0x5.0mm_HandSolde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
YMF288: YMF288

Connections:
4016_EN: R12.2, R13.2, U7.15 (Q5), U8.1 (S), U9.1 (S), U10.1 (S)
+5V: BU9480F1.8, J2.2, J4.1, J8.1, R1.1, R4.1, U1.16 (VCC), U2.14 (VCC), U3.5 (V+), U6.16 (VCC), U7.14 (D5), U7.16 (VCC), U8.16 (VCC), U9.16 (VCC), U10.16 (VCC), X1.4 (VCC), YMF288.12, YMF288.19, YMF288.22, YMF288.27
+5VA: J3.30, J9.30
A0: J2.25, J3.13, J9.13
A0_Chip: U10.7 (Zb), YMF288.20
A0_buf: U6.12 (Q4), U10.6 (I1b)
A1: J2.23, J3.12, J9.12
A1_Chip: U10.4 (Za), YMF288.21
A1_buf: U6.15 (Q5), U10.3 (I1a)
A2: J2.21, J3.11, J9.11
A3: J2.19, J3.10, J9.10
A4: J2.17, J3.9, J9.9
A5: J2.15, J3.8, J9.8
A6: J2.13, J3.7, J9.7
A7: J2.11, J3.6, J9.6
A8: J2.9, J3.5, J9.5
A9: J2.7, J3.4, J9.4
A10: J2.5, J3.3, J9.3
A11: J2.3, J3.2, J9.2
A12: J2.6, J4.3, J8.3
A13: J2.8, J4.4, J8.4
A14: J2.10, J4.5, J8.5
Addr_A1: J2.14, U10.2 (I0a)
Addr_A13: J2.16, U10.5 (I0b)
Addr_A14: J2.18, U1.14 (A0)
Addr_R-W: J2.22, U1.13 (A1)
Addr_ROMSEL: J2.20, U1.15 (E)
Aud: J4.15, J8.15
AudIn: J8.16, R6.1, R9.1
CIRAM_A10: J3.18, J9.18
CIRAM_CE: J4.18, J8.18
CS_: U1.11 (O1), U10.14 (I0c)
CS_Chip: U10.12 (Zc), YMF288.17
CS_buf: U2.6, U10.13 (I1c)
D0: J4.13, J8.13, U9.2 (I0a)
D0_Chip: U9.4 (Za), YMF288.2
D0_buf: U7.2 (Q0), U9.3 (I1a)
D1: J4.12, J8.12, U9.5 (I0b)
D1_Chip: U9.7 (Zb), YMF288.3
D1_buf: U7.5 (Q1), U9.6 (I1b)
D2: J4.11, J8.11, U6.14 (D5), U9.14 (I0c)
D2_Chip: U9.12 (Zc), YMF288.4
D2_buf: U7.7 (Q2), U9.13 (I1c)
D3: J4.10, J8.10, U6.13 (D4), U9.11 (I0d)
D3_Chip: U9.9 (Zd), YMF288.5
D3_buf: U7.10 (Q3), U9.10 (I1d)
D4: J4.9, J8.9, U6.3 (D0), U7.3 (D0), U8.2 (I0a)
D4_Chip: U8.4 (Za), YMF288.6
D4_buf: U6.2 (Q0), U8.3 (I1a)
D5: J4.8, J8.8, U6.4 (D1), U7.4 (D1), U8.5 (I0b)
D5_Chip: U8.7 (Zb), YMF288.7
D5_buf: U6.5 (Q1), U8.6 (I1b)
D6: J4.7, J8.7, U6.6 (D2), U7.6 (D2), U8.14 (I0c)
D6_Chip: U8.12 (Zc), YMF288.8
D6_buf: U6.7 (Q2), U8.13 (I1c)
D7: J4.6, J8.6, U6.11 (D3), U7.11 (D3), U8.11 (I0d)
D7_Chip: U8.9 (Zd), YMF288.9
D7_buf: U6.10 (Q3), U8.10 (I1d)
FF_Reset: U2.8, U6.1 (~Mr), U7.1 (~Mr)
GND: BU9480F1.3, C1.1, C2.2, C3.1, C4.1, C5.1, C7.1, C8.2, J1.1, J2.1, J3.1, J9.1, R2.2, U1.1 (E), U1.8 (GND), U2.7 (GND), U3.2 (V-), U6.8 (GND), U7.8 (GND), U8.8 (GND), U8.15 (OE), U9.8 (GND), U9.15 (OE), U10.8 (GND), U10.15 (OE), X1.2 (GND), YMF288.1, YMF288.14, YMF288.16, YMF288.18
GND1: J3.16, J9.16
IRQ: J3.15, J9.15, YMF288.15
M2: J2.4, J4.2, J8.2
unnamed: BU9480F1.1, R8.2
unnamed: BU9480F1.2, C2.1
unnamed: BU9480F1.4, R5.1
unnamed: BU9480F1.5, YMF288.26
unnamed: BU9480F1.6, YMF288.24
unnamed: BU9480F1.7, YMF288.23
unnamed: C1.2, R4.2, YMF288.11
unnamed: C3.2, R12.1, U2.4
unnamed: C4.2, R13.1, U2.1, U2.2
unnamed: C5.2, R14.1, U2.12, U2.13
unnamed: C6.1, R5.2, R8.1
unnamed: C6.2, C7.2, R1.2, R2.1, U3.1 (+)
unnamed: C8.1, R3.2
unnamed: C9.1, R9.2
unnamed: C9.2, R7.2, U3.4
unnamed: J4.16, R6.2
unnamed: R3.1, R7.1, U3.3 (-)
unnamed: R14.2, U2.3, U2.5
unnamed: U2.9, U2.10, U2.11
unnamed: X1.3 (OUT), YMF288.28
OUT1: J1.2, U1.2 (A0), U1.3 (A1), U6.9 (Cp)
OUT1_: U1.7 (O3), U7.9 (Cp)
PPU_A0: J3.25, J9.25
PPU_A1: J3.24, J9.24
PPU_A2: J3.23, J9.23
PPU_A3: J3.22, J9.22
PPU_A4: J3.21, J9.21
PPU_A5: J3.20, J9.20
PPU_A6: J3.19, J9.19
PPU_A7: J4.20, J8.20
PPU_A8: J4.21, J8.21
PPU_A9: J4.22, J8.22
PPU_A10: J4.23, J8.23
PPU_A11: J4.24, J8.24
PPU_A12: J4.25, J8.25
PPU_A13: J4.26, J8.26
PPU_A13_: J4.19, J8.19
PPU_D0: J3.26, J9.26
PPU_D1: J3.27, J9.27
PPU_D2: J3.28, J9.28
PPU_D3: J3.29, J9.29
PPU_D4: J4.30, J8.30
PPU_D5: J4.29, J8.29
PPU_D6: J4.28, J8.28
PPU_D7: J4.27, J8.27
PPU_RD: J3.17, J9.17
PPU_WR: J4.17, J8.17
R-W: J2.27, J3.14, J9.14
ROMSEL: J2.28, J4.14, J8.14

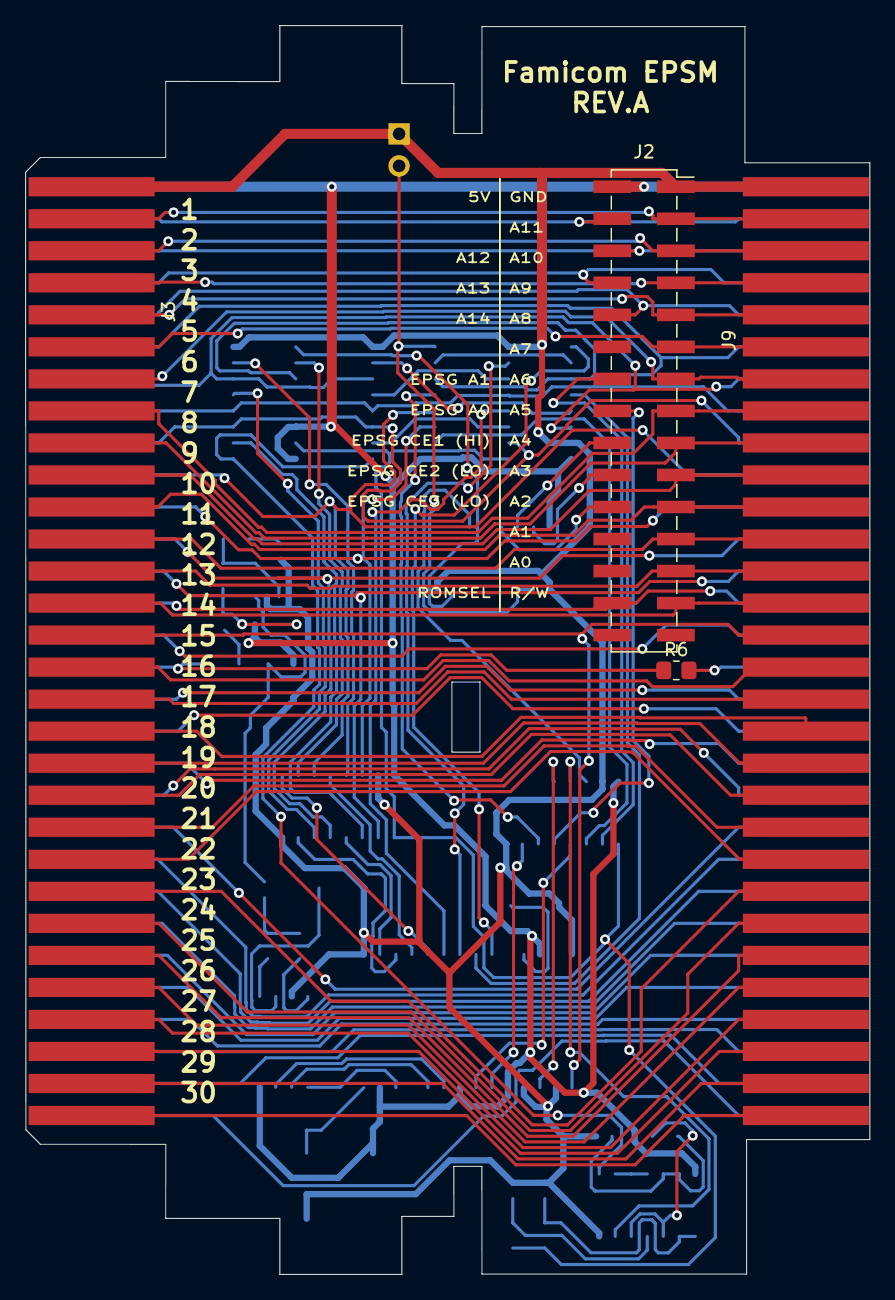
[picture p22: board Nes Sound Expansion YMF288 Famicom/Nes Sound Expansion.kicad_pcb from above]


Board: 2 copper layers, 67.0 x 99.0 mm, 38 parts (34 on the bottom side), 112 nets.

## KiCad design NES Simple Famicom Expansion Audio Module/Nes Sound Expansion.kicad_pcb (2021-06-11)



Board: 2 copper layers, 21.1 x 68.3 mm, 5 parts (2 on the bottom side), 6 nets.

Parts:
J3: EXP 1-24; PinHeader_1x24_P2.54mm_Vertical
J4: EXP 25-48; PinHeader_1x24_P2.54mm_Vertical
R1, R2, R3: 47k; R_0805_2012Metric

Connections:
AudIn: J3.3, R1.2, R2.2, R3.2
GND: J3.2, J4.2
unnamed: J3.1, J4.1
unnamed: J3.6, R3.1
unnamed: J3.9, R1.1
unnamed: J4.9, R2.1

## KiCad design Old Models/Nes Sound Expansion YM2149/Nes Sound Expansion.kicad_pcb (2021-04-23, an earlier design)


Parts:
C1, C2, C3, C4, C5, C6, C7, C9, C10: C; C_Disc_D5.1mm_W3.2mm_P5.00mm
J1: EXP 25-48; PinHeader_1x24_P2.54mm_Vertical
J2: EXP 1-24; PinHeader_1x24_P2.54mm_Vertical
J3: NES-SNES Port1; PinHeader_1x07_P2.54mm_Vertical
J4: NES-SNES Port2; PinHeader_1x07_P2.54mm_Vertical
J5: AUD Out; PinHeader_1x04_P2.54mm_Vertical
J6: EN Switch; PinHeader_1x04_P2.54mm_Vertical
R1, R2, R3, R6: 1Kohm; R_Axial_DIN0207_L6.3mm_D2.5mm_P10.16mm_Horizontal
R4, R5: 3kohm; R_Axial_DIN0207_L6.3mm_D2.5mm_P10.16mm_Horizontal
U1, U2, U5: 74LS175; DIP-16_W7.62mm
U3: YM2149; DIP-40_W15.24mm
U4: 4081; DIP-14_W7.62mm
U6: 4011; DIP-14_W7.62mm
U7: 4070; DIP-14_W7.62mm

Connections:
+5V: C2.2, C3.2, C4.2, C5.2, C6.2, C9.2, C10.2, J1.1, J2.1, J3.1, J4.1, U1.16 (VCC), U2.16 (VCC), U3.28 (BC2), U3.40 (VCC), U4.14 (VDD), U5.12 (D2), U5.16 (VCC), U6.14 (VDD), U7.14 (VDD)
GND: C2.1, C3.1, C4.1, C5.1, C6.1, C7.2, C9.1, C10.1, J1.2, J2.2, J3.7, J4.7, J5.3, J5.4, R4.2, U1.8 (GND), U2.8 (GND), U3.1 (VSS), U4.7 (VSS), U5.8 (GND), U6.7 (VSS), U7.7 (VSS)
unnamed: C1.1, J5.1, J5.2, R5.1
unnamed: C1.2, R1.1, R2.1, R3.1, R4.1
unnamed: C7.1, R6.2, U6.1, U6.2
unnamed: J1.4, R6.1, U7.1
unnamed: J1.5, U5.4 (D0)
unnamed: J1.6, J3.3, J4.3
unnamed: J1.12, J3.2
unnamed: J1.14, J3.4
unnamed: J1.21, U1.4 (D0)
unnamed: J1.22, U1.5 (D1)
unnamed: J1.23, U1.12 (D2)
unnamed: J1.24, U1.13 (D3)
unnamed: J2.11, J4.2
unnamed: J2.19, J4.4
unnamed: J2.21, R5.2
unnamed: J2.24, U3.22 (CLOCK)
unnamed: R1.2, U3.3 (A)
unnamed: R2.2, U3.4 (B)
unnamed: R3.2, U3.38 (C)
unnamed: U1.1 (~Mr), U2.1 (~Mr), U5.1 (~Mr), U5.15 (Q3)
unnamed: U1.2 (Q0), U2.13 (D3), U3.37 (DA0)
unnamed: U1.7 (Q1), U2.12 (D2), U3.36 (DA1)
unnamed: U1.9 (Cp), U2.9 (Cp), U5.9 (Cp), U7.3
unnamed: U1.10 (Q2), U2.5 (D1), U3.35 (DA2)
unnamed: U1.15 (Q3), U2.4 (D0), U3.34 (DA3)
unnamed: U2.2 (Q0), U3.33 (DA4)
unnamed: U2.7 (Q1), U3.32 (DA5)
unnamed: U2.10 (Q2), U3.31 (DA6)
unnamed: U2.15 (Q3), U3.30 (DA7)
unnamed: U3.27 (BDIR), U4.2, U5.3 (~Q0)
unnamed: U3.29 (BC1), U4.3
unnamed: U4.1, U5.2 (Q0), U5.5 (D1)
unnamed: U5.10 (Q2), U5.13 (D3)
unnamed: U6.3, U6.5, U6.6
unnamed: U6.4, U7.2



Board: 2 copper layers, 99.1 x 88.9 mm, 28 parts (2 on the bottom side), 37 nets.

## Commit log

2021-04-23 Uploaded all current files
    [Nes Sound Expansion-B_Cu.gbr, Nes Sound Expansion-B_Mask.gbr, Nes Sound Expansion-B_Paste.gbr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]
2021-04-23 changed reset circuit
    [Nes Sound Expansion.kicad_pcb, Nes Sound Expansion.sch]
2021-05-06 Fixed floating signals and famicom exp audio
    Addressing issues caused by floating signals when a cart without hardware addressing is used
    Added famicom expansion resistors to all 3 popular EXP pins.
    [Nes Sound Expansion.kicad_pcb, Nes Sound Expansion.sch]
2021-05-06 minor update
    [Nes Sound Expansion.kicad_pcb, Nes Sound Expansion.sch]
2021-05-07 Updated mixing on the Famicom version
    [Nes Sound Expansion.kicad_pcb, Nes Sound Expansion.sch]
2021-05-15 Addressing circuit added for using 401C-401F address range
    [EPSG 401C-F Addressing circuit.sch]
2021-05-16 Added IRQ from the YMF288
    [Nes Sound Expansion.kicad_pcb, Nes Sound Expansion.sch]
2021-05-24 Added logo, 3.5mm 3d module, removed unused stuff
    [Nes Sound Expansion-B_Cu.gbr, Nes Sound Expansion-B_Mask.gbr, Nes Sound Expansion-B_Paste.gbr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]
2021-05-26 Redesigned to fit a Famicom MMC cart and updated readme
    [Nes Sound Expansion.kicad_pcb, Nes Sound Expansion.sch]
2021-05-26 minor updates
    [Nes Sound Expansion.kicad_pcb]
2021-05-26 Folder rename
    [Nes Sound Expansion-B_Cu.gbr, Nes Sound Expansion-B_Mask.gbr, Nes Sound Expansion-B_Paste.gbr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]
2021-06-11 Added amplification for both famicom and nes model
    [Nes Sound Expansion-B_Cu.gbr, Nes Sound Expansion-B_Mask.gbr, Nes Sound Expansion-B_Paste.gbr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]
2021-09-01 Updated 401C-F addressing circuit
    [EPSG 401C-F Addressing circuit.kicad_pcb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]
2021-09-01 Added M2 to the addressing circuit and famicom daughterboard connector
    [EPSG 401C-F Addressing circuit.sch, Nes Sound Expansion.kicad_pcb, Nes Sound Expansion.sch]
2022-05-11 Removed power switch and updated resistor values
    [Nes Sound Expansion.kicad_pcb, Nes Sound Expansion.sch]
2022-05-11 Forgot to press save after editing resistor values
    [Nes Sound Expansion.sch]
2022-05-15 Add perpendicular Famicom PCB design
    [EPSM-Famicom-rounded.kicad_pcb, EPSM-Famicom.kicad_pcb, EPSM-Famicom.kicad_sch]
2022-05-22 Flip cartridge connection to back instead of front
    [EPSM-Famicom-blank.kicad_pcb, EPSM-Famicom-rounded.kicad_pcb, EPSM-Famicom.kicad_sch]
2022-06-15 Updated Rev.A to Rev.A1
    [Nes Sound Expansion.kicad_pcb]
2022-11-19 Added improved addressing circuit
    [EPSG 401C-F Addressing circuit.kicad_pcb, EPSG 401C-F Addressing circuit.sch, EPSM 401C-F Addressing circuit.kicad_pcb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]
2023-01-01 Update FC-H EPSM
    - Upgrade to 4 layers
    - Use same amplifier circuit as NES EPSM
    - Optimize logic chip pin assignment
    [EPSM-Famicom-rounded.kicad_pcb, EPSM-Famicom.kicad_pcb, EPSM-Famicom.kicad_sch]
2023-01-03 Reposition all SMD components to be on top
    [EPSM-Famicom-rounded.kicad_pcb, EPSM-Famicom.kicad_pcb, EPSM-Famicom.kicad_sch]
2023-01-22 Incremental improvements
    - Add ground plane around audio traces
    - Nudge audio jack for better allowance
    - Add stitching vias in audio amplifier zone
    [EPSM-Famicom.kicad_pcb]
2023-01-22 Clarify EPSM chip enable and address net names
    [EPSM-Famicom.kicad_pcb, EPSM-Famicom.kicad_sch]
2023-01-22 Add 401C-F decoding daughterboard PCB for EPSM FC
    [EPSM-Famicom-Daughterboard-rounded.kicad_pcb, EPSM-Famicom-Daughterboard.kicad_pcb, EPSM-Famicom-Daughterboard.kicad_sch]
